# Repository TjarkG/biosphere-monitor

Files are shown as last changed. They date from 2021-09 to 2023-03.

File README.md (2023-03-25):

# Getting started with the Biosphere monitor command line tool

Get the repository and all its dependencies by running
`/bin/bash -c "$(curl -fsSL  https://raw.githubusercontent.com/TjarkG/biosphere-monitor/main/Shell/install.sh)"`

The Command line interface is started with `./biosphere`,
followed by a Port number (e.g. `/dev/ttyUSB0`) and optional arguments,
which can occur in any order, listed below:

* -h    show this help message
* -r    show current reading in Command line Output
* -rm   current output in machine-readable formate
* -s    show all saved readings. use pipes to save to a file
* -sc   same as -s, but with progress Updates on the Terminal. Use it to see the progress while piping
* -f    synchronize time
* -i    set measurement intervall in s, use -i? to get current intervall
* -t    run self test
* -ct   set current ambient Temperature(°C), used for Offset Calibration
* -delete delete Flash
* -gh   get current ADC reading of external input
* -ltn  set light on time, use -ltn? to get current setting
* -ltf  set light off time, use -ltf? to get current setting
* -lt   set light threshold, 0 for no threshold, use -lt? to get current setting

After cloning, generate makefiles with cmake:
```
mkdir cmake-build-debug
cd cmake-build-debug
cmake ..
```
and Compile the different programs:

* Command Line Tool: `make biosphere && ./biosphere /dev/ttyUSB0 -r`
* Graphical Configurator: `make bioGui`
* Microcontroller: `make Microcontroller.elf`

Check your data for Gaps with
`gawk -f Shell/gaps.awk gap=60 Documentation/Sample_Output.csv`
(gap is the intervall in s, each following argument is a Path to File to be checkt)

And convert it to an Excel Spreadsheet with
`soffice --convert-to xlsx --outdir ~/Dokumente/VS_Code/biosphere-monitor/Documentation Documentation/Sample_Output.csv --infilter=CSV:44,34,UTF8,true,3/10/4/10`

Complete Documentation (in German) can be found in /Documentation/Manual.pdf

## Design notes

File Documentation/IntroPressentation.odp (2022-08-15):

## Messgeräte für Biosphären

## Inhalt

- Was wird gemessen?
- Wofür braucht man das?
- Wie komme ich an die Daten?

## Was wird gemessen?

## Wofür braucht man das?

## Wie komme ich an die Daten?

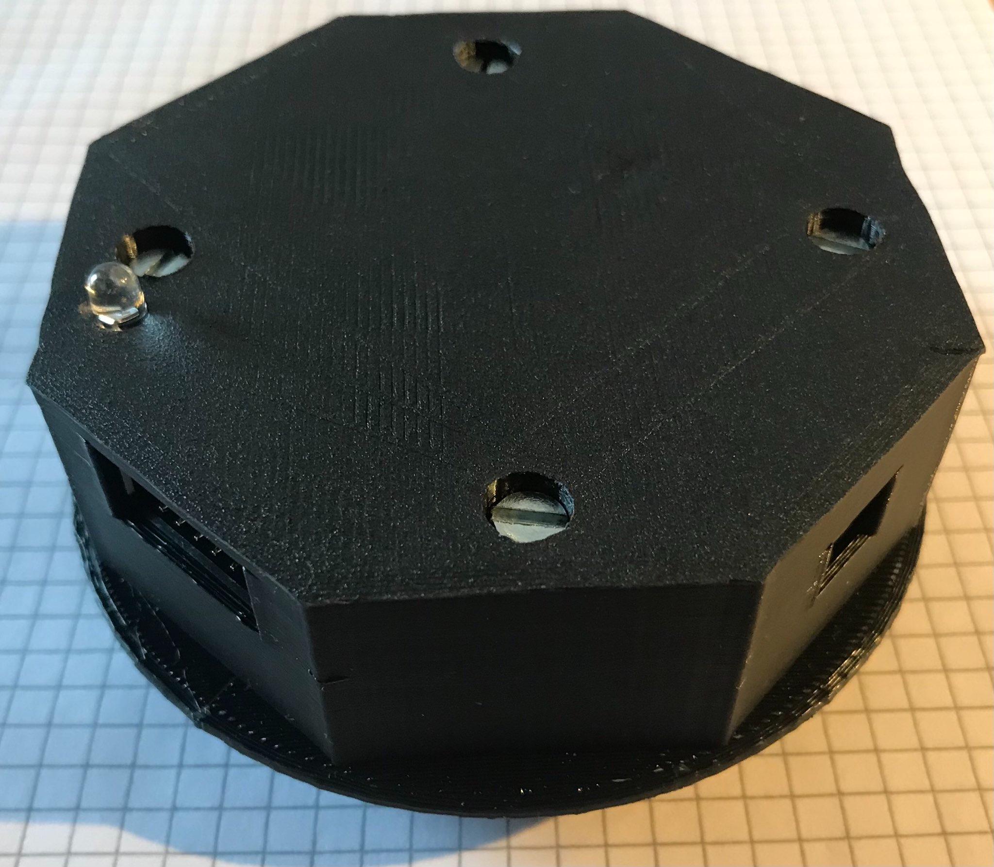
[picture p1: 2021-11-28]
Documentation/pic/Komplett.jpeg

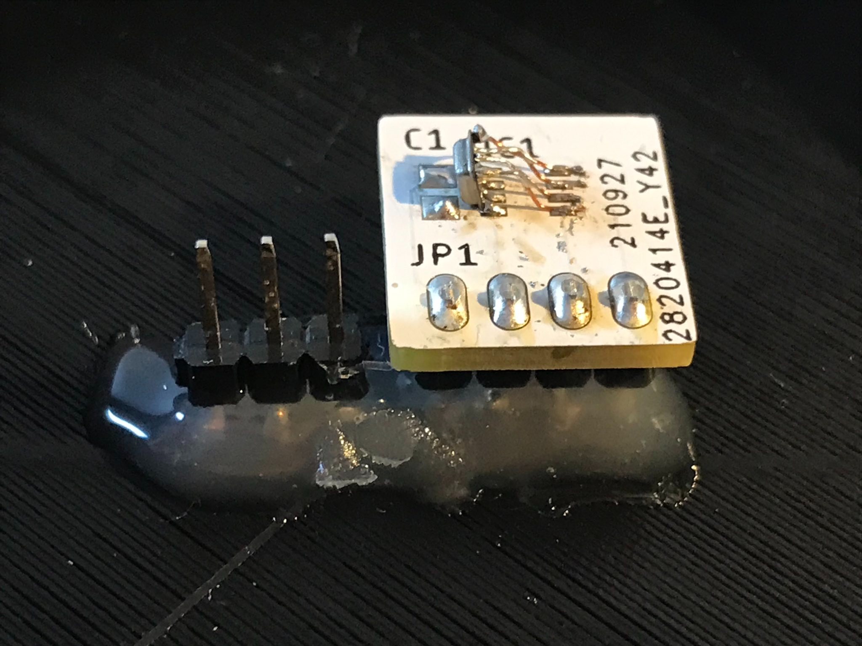
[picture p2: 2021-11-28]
Documentation/pic/Stiftleisten.jpeg

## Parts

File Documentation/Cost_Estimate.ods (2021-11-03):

Item | Preis /Stück | Preis / Fix |  | Preis mit vorhandenen Platinen etc.
Bauteile | 15,57 € | 5,95 € | Bauteile | 18,07 €
FTDI/USB | 1,98 € | 1,17 € | FTDI Adapter | 1,98 €
Platinen | 1,42 € | 14,03 € | Versand | 5,59 €
Filament | 0,00 € | 15,90 €
Schrauben | 2,99 € | 0,00 €
O Ring | 0,00 € | 0,00 €
 | 21,96 € | 37,05 € |  | 25,64 €

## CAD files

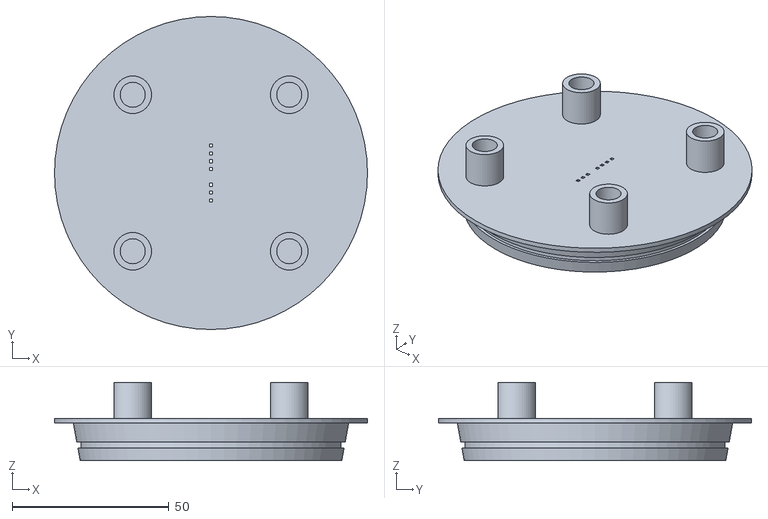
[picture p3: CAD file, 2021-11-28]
Hardware/MainPlate.stl
100.0 x 100.0 x 25.0

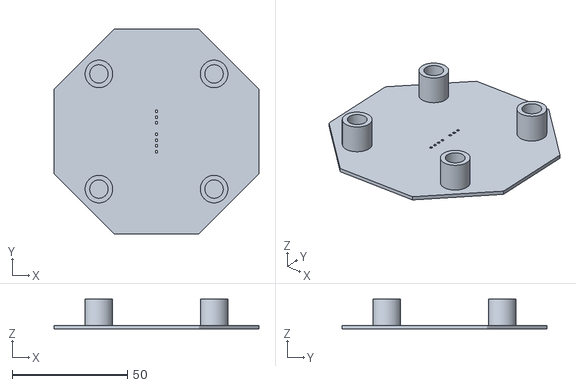
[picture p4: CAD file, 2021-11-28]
Hardware/MainPlateFlat.stl
89.0 x 89.0 x 13.0

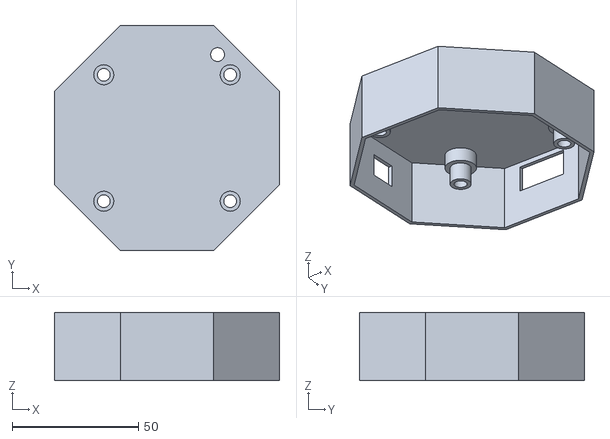
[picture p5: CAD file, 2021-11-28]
Hardware/Cap.stl
89.0 x 89.0 x 27.0

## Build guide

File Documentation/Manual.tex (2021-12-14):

\documentclass[12pt, a4paper, oneside]{report}
\usepackage[ngerman]{babel}
\usepackage{graphicx}
\usepackage{mathtools}
\usepackage{listings}
\usepackage{color}
\usepackage{float}
\sloppy
\usepackage[citecolor=black, colorlinks=true, urlcolor=blue, linkcolor=black]{hyperref}

\definecolor{mygreen}{rgb}{0,0.6,0}
\definecolor{mygray}{rgb}{0.5,0.5,0.5}
\definecolor{mymauve}{rgb}{0.58,0,0.82}
\definecolor{amber}{rgb}{0.8, 0.5, 0.2}

    \title{\textbf{Biosphären Mess- und Überwachungsgeräte -- Funktionsprinzipien und Bedienungsanleitung}}
    \author{Tjark Gaudich}
    \date{November 2021}
    
    \addtolength{\topmargin}{-2cm}
    \addtolength{\textheight}{2cm}
\begin{document}
\lstset{basicstyle=\footnotesize, language=C, keywordstyle=\color{blue}, tabsize=4}

\pagenumbering{Alph}
\begin{titlepage}
\maketitle
\thispagestyle{empty}
\end{titlepage}
\pagenumbering{arabic}

\section{Vorwort}
Das folgende Dokument soll gleichzeitig als Dokumentation und Bedienungsanleitung für die Biosphären Umweltmessgeräte ("die Geräte") dienen, die ich für den Astrobiologie Projektkurs 2021/2022 bei Herr Krobbach entwickelt habe. Damit soll eine Nutzung und Wartung dieser Geräte weit über den Zeitraum meiner Schullaufbahn hinaus ermöglicht werden. Besonderer Fokus wird deshalb auf die Kommunikation mit dem PC zum Auslesen der Messwerte gelegt, da dieser vulnerabel für Änderungen des Betriebssystems ist, doch auch alle anderen Aspekte der Geräte sollen so sehr vertieft werden, dass sie ohne großes Vorwissen verstanden und repariert werden können. Sämtliche Quelldateien sind zusammen mit dieser Dokumentation auf 
GitHub\cite{Github} frei zugänglich.
\tableofcontents
\listoffigures

\chapter{Mechanik}

Mechanisch lassen sich die Geräte in vier Komponenten unterteilen:
eine Grundplatte (in \autoref{fig:Querschnitt} Dunkelgrau), an der alle andere Teile und das Glas der Biosphäre befestigt werden, eine Platine mit Sensoren im Inneren (nicht gezeigt) und die Hauptplatine (grün) außen sowie ein Deckel (hellgrau), der die Elektronik vor Beschädigungen schützt.
\begin{figure}[h]
	\centering
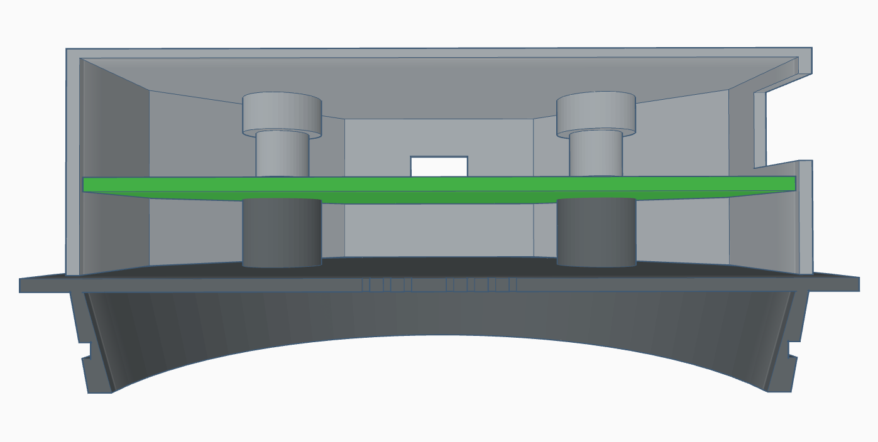
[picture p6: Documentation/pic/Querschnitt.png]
	
	\caption{Querschnitt durch das Gerät}
	\label{fig:Querschnitt}
\end{figure}
\\Auf die Platinen wird in \autoref{ch:elektronik} näher eingegangen, hier reicht es uns zu wissen das die unterer Platine nur über ihren Stecker befestigt wird und die obere ein Achteck von 85mm Durchmesser ist, vier Löcher mit je 50mm Abstand zueinander und 4mm Durchmesser zur Befestigung hat und 1,6mm Dick ist.

Deckel und Grundplatte sind beide aus PLA 3d gedruckt. Dabei wurde eine Auflösung von 0,2mm bei 100\% Infill verwendet
\section{Grundplatte}
Entsprechend dieser Maße ist die Oberseite der Grundplatte mit vier Röhren ausgestattet, in die M4 Einschraubmuffen montiert werden. Interessant ist jedoch die Unterseite, die in das Gurkenglas eingeklebt wird. Da die Luftmenge in der Biosphäre konstant ist kommt es bei Temperaturänderungen zu einer Druckänderung nach  dem Gesetz von Amontons \cite[S.~119]{Tafelwerk}, denen die Grundplatte und ihre Verklebung standhalten müssen. $p_0$ und $T_0$ sind dabei Druck und absolute Temperatur beim Verschließen der Biosphäre.
\begin{align}
\frac{p_0}{T_0} = \frac{p_1}{T_1} \footnote{}
\iff \Delta p = T  \times \frac{p_0}{T_0} - p_0
\label{eq:pressure}
\end{align}
Nehmen wir an, das die Biosphäre bei 20°C (293K) und Normaldruck verschlossen wurde und sich im Schlimmsten Falle auf 100°C (373K) aufgeheizt hat (darüber ist ihr Inhalt vermutlich tot, weshalb die Abdichtung irrelevant wird),
\begin{align}
\Delta p = 373K  \times \frac{1013hPa}{293K} - 1013hPa \approx 277hPa
\label{eq:pressure100C}
\end{align}
so ergibt sich nach \autoref{eq:pressure100C} ein Druckunterschied von 277hPa. Diese Druckfestigkeit mit einer Silikon Verklebung zu erreichen ist relativ einfach, beim Übergang zwischen Grundplatte und anschließendem Ring wird sie jedoch zu Herausforderung. Um eine höhere Festigkeit zu erreichen wurde dieser Übergang nach dem Druck zusätzlich mit einem Lötkolben verschmolzen. Diese Kombination hielt beim Anschließen eines Kompressors an einen Modifizierten Deckel etwa 300hPa Überdruck stand.

Falls sich zeigen sollte, das dies nicht ausreicht wäre eine Verdickung des Übergangs oder der Druck aus einem festeren Material, z.B.~Nylon, empfehlenswert.

Bei der Verklebung der Grundplatte mit dem Glas der Biosphäre sollte Aquariensilikon verwendet werden, da Sanitärsilikon für die Oranismen in der Biosphäre schädliche Zusatzstoffe enthalten kann.

\begin{figure}[h]
	\centering
	
	\caption{Fertig montierte Stiftleisten mit Sensorplatine}
	\label{fig:Stiftleisten}
\end{figure}

In der Platte befinden sich sieben Löcher, durch die Stiftleisten gesteckt werden um die Sensoren im Inneren mit der Hauptplatine zu verbinden. Dabei wird eine Stiftleiste von oben eingesteckt, mit Epoxidharz (UHU Endfest 3000) verklebt, von unten eine weitere Stiftleiste angelötet und die Lötstelle mit Heißkleber fixiert.

\section{Deckel}
Der Deckel besteht aus einem Achteck mit Abschlussplatte und eingesenkten Löchern, durch die er und die Hauptplatine mit vier M4~x~16 Schrauben an der Grundplatte befestigt werden. Beim Entfernen muss darauf geachtet werden, dass keine Kabel eingesteckt sind und der Deckel gerade nach oben abgezogen wird, um die durch ihn vorstehende Fotodiode nicht zu beschädigen.
\\
\begin{figure}[h]
	\centering
	
	\caption{Vollständig montiertes Gerät}
	\label{fig:Komplett}
\end{figure}

\chapter{Elektronik}
\label{ch:elektronik}
Die Elektronik besteht aus der Hauptplatine, die in fünf Funktionsblöcke unterteilt ist, einer Adapterplatine für den Luftsensor und einem ansteckbaren Bodenfeuchtigkeitssensor. Die Funktionsblöcke ensprechen den Seiten von "`biosphereMonitor.sch"', die Adapterplatine findet sich in "`Adapter.sch"'. Beide Schaltpläne und ihre dazugehörigen Platinen sind mit Eagle verfasst worden.

Eagle ist als Demoversion und für Bildungszwecke kostenlos und lässt sich unter \url{https://www.autodesk.de/products/eagle/free-download}\\ herunterladen.
\section{Mikrocontroller}
\label{sec:Mikrocontroller}
Alls Mikroncontroller findet ein ATxmega32A4AU\cite{ds:xmega} oder 16A4AU von Microchip Verwendung (IC1).

\begin{figure}[h]
	\centering
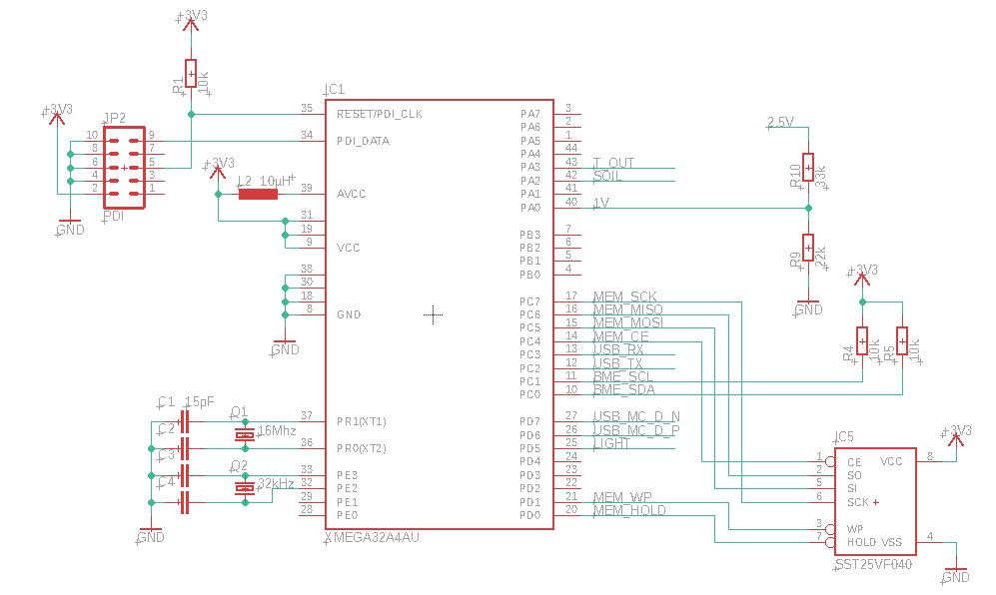
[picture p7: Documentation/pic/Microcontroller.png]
	
	\caption{Schaltplan Mikrocontroller}
	\label{fig:Microcontroller}
\end{figure}

\begin{figure}[h]
	\centering
\begin{tabular}{c|l}
	Pins & Funktion\\
	\hline
	10, 11 & TWI C zum Luftsensoren (\autoref{sec:Adapterplatine})\\
	12 (Tx), 13 (Rx)& UART0 zum USB UART Wandler (\autoref{sec:USB-UART Wandler}), \\&in Revision 1.0 vertauscht\\
	14 - 17 & Flash Spi Schnittstelle\\
	20, 21 & Flash Kontrollsignale\\
	25 & Lichtsensor (\autoref{sec:Außensensoren}), bei Steigender Flanke \\&Pin Change Interuppt\\
	26, 27 & Reserviert für eingebautes USB\\
	32, 33 & Q2, 32.768kHz Uhrenquartz für die Realtimeclock\\
	34, 35 & PDI Programmierschittstelle\\
	36, 37 & Q1, 4 - 20MHz Hauptquartz, (16MHz Standard)\\
	40 & 1V Referenzspannung, über R9/10 aus 2,5V\\
	42 & ADC In Bodenfeuchtigkeitssensor (s. \autoref{sec:Bodenfeuchtigkeitssensor}) \\
	43 & ADC In Temperatursensor (s. \autoref{sec:Außensensoren})\\
\end{tabular}
	\caption{Pinbelegung Mikrocontroller}
\end{figure}
Dieser wird über die PDI Schnittstelle auf JP2 Programmiert. Das Pinout dieses Steckers ist kompaktibel mit dem des AVR ISP MK II Programiergeräts von Atmel/Microchip.
Die Frequenz von Q1 muss in $main.c$ und $makefile$ als F\_CPU eingetragen werden

Beim Flash handelt es sich um einen 4Mb 

\section{Stromverteilung}
\label{sec:Stromverteilung}

\section{USB-UART Wandler}
\label{sec:USB-UART Wandler}

\pagebreak
\section{Außensensoren}
\label{sec:Außensensoren}
Außen werden zwei Messwerte erhoben: Temperatur und Helligkeit.

Die Temperatur wird mit einem analogen Temperatursensor vom Typ LM35 \cite{ds:temp} der an TP6 eine Spannung von
$ 10mV * t~(in~^\circ C)$ anlegt. Diese wird vom Mikrocontroller (\autoref{sec:Mikrocontroller}) gemessen.

\begin{figure}[h]
	\centering
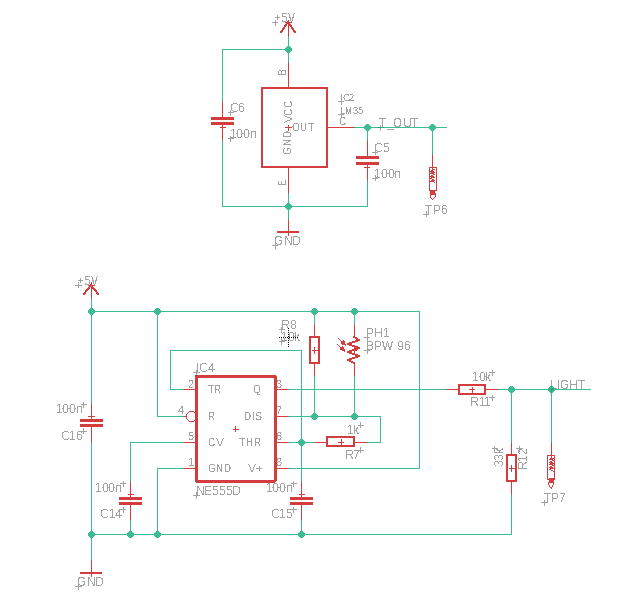
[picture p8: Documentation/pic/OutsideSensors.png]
	
	\caption{Schaltplan Außensensoren}
	\label{fig:Außensensor}
\end{figure}

Die Helligkeit wird mit einer Fotodiode vom Typ BPW96 \cite{ds:light} gemessen, die parralel zu R8 im Timingpfad des NE555 eingebaut ist. R11 und 12 teilen die Spannung des Ausgangssignales von 5V auf 3,3V, so das an TP7 ein 3,3V Rechtecksignal mit einer Frequenz exponential zur Lichteinstrahlung anliegt. Um die Einstrahlung zu bestimmen ist im Mikrocontroller eine Funktion fest einprogrammiert, die anhand der Messreihe aus $Lux~Messurments.ods$ bestimmt wurde. Die Formel hat das Format $f(x)=a \cdot x^b + c$. Um diese Formel zu füllen werden zunächst drei Punkte, erster, letzter und mittlerer aus der Messreihe, ausgewählt.

\begin{figure}[h]
\centering
\begin{tabular}{c|c|c}
	Nr. & x & y\\
	\hline
	1 & 1,27 & 0\\
	2 & 3,93 & 442\\
	3 & 6,21 & 1880\\
\end{tabular}
\end{figure}

Diese werden in \autoref{eq:lightB} bis \ref{eq:lightC} eingsetzt, um \autoref{eq:light} zu erhalten. Die dadurch erreichte Annäherung ist in \autoref{fig:Licht} oder $Lux~Messurments.ods$\footnote{\url{https://github.com/TjarkG/biosphere-monitor/blob/main/Documentation/Lux\%20Messurments.ods}} zu erkennen.

\begin{align}
y_3-y_1=\frac{y_2-y_1}{b^{x_2}-b^{x_1}}\cdot(b^{x_3}-b^{x_1}) \iff b \approx 1,65
\label{eq:lightB}
\end{align}

\begin{align}
a=\frac{y_2-y_1}{b^{x_2}-b^{x_1}} = 83,75
\label{eq:lightA}
\end{align}

\begin{align}
c = -a\cdot b^{x_1} + y_1 = -158,26
\label{eq:lightC}
\end{align}

\begin{align}
\label{eq:light}
f(x) = 83,75 \cdot 1,65^x -158,26
\end{align}

\begin{figure}[H]
	\centering
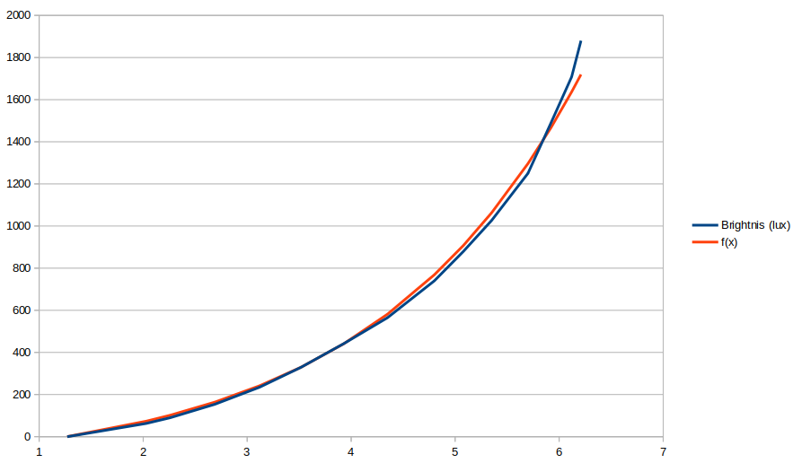
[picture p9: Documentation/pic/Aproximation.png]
	
	\caption{Annäherung Messwerte}
	\label{fig:Licht}
\end{figure}
\pagebreak
Dieser Werte sind auch in die Entsprechende Funktion in $main.c$\footnote{\url{https://github.com/TjarkG/biosphere-monitor/blob/main/Microcontroller/main.c}} eingesetzt
Sie sind momentan fest einprogrammiert, auch wenn eine Möglichkeit sie zu konfigurieren sinnvoll wäre.
\begin{lstlisting}
unsigned int getLight(void)  //returns iluminace in lux
{
	if(lightFnom < 1200)     //Sensor cutoff Frequency
		return 0;
	return ((66.46 * pow(1.732, (lightFnom/1000.0)) ) - 133.5);
}
\end{lstlisting}

\section{Anschlüsse Innensensoren}
\label{sec:Innensensoren}

\section{Adapterplatine}
\label{sec:Adapterplatine}

\section{Bodenfeuchtigkeitssensor}
\label{sec:Bodenfeuchtigkeitssensor}

\chapter{Software}
Die Software besteht aus zwei Teilen, dem Code für den Mikrocontroller und dem Ausleseprogramm für den PC. Um die eine installieren und die andere nutzen zu können müssen beide zunächst gecloned und ihre abhängigkeiten installiert werden. Die Befehle können für Debian Linux Varianten einfach kopiert werden, für andere Distributionen oder MacOS ist \lstinline|sudo apt-get| durch das lokale Eqvivallent zu ersetzen
\section{Instalation}
\label{sec:Instalation}
Sämtliche benötigte Software kann durch ausführen von
\begin{lstlisting}
/bin/bash -c "$(curl -fsSL 
https://raw.githubusercontent.com/
TjarkG/biosphere-monitor/main/Shell/install.sh)"
\end{lstlisting}
Installiert werden. Der Script wurde unter Ubuntu und Alpine Linux getestet. Falls dies nicht funktioniert kann die Installation auch manuel durchgeführt werden:
Zum Clonen muss zunächst $git$ installiert werden.
\begin{lstlisting}
$ sudo apt-get install git
\end{lstlisting}
Dann kann das Repository gecloned
\begin{lstlisting}
$ git clone https://github.com/TjarkG/biosphere-monitor
\end{lstlisting}
Und in den neuen Ortnder gewechselt werden.
\begin{lstlisting}
$ cd biosphere-monitor
\end{lstlisting}
Um die PC Software compilen zu können ist außerdem GCC als Kompiler notwendig.
\begin{lstlisting}
$ sudo apt-get install gcc
\end{lstlisting}
Die aktuelle Version kann jetzt jeweils mit
\begin{lstlisting}
$ cc PC/biosphere.c -o PC/biosphere
$ ./PC/biosphere /dev/ttyUSB0 -r
\end{lstlisting}
kompilert und ausgeführt werden. 
\pagebreak

Um die Mikrocontroller Firmware aktualisieren zu können, werden neben der Hardware (\autoref{sec:Mikrocontroller})  eine ganze Reihe Hilfsprogramme benötigt. Eine Erläuterungen zu ihrer Funktion findet sich unter \cite{UbuntuAVR}
\begin{lstlisting}
$ sudo apt-get install avr-libc binutils-avr gcc-avr avrdude make
\end{lstlisting}
Das Upload der Firmware erfolgt mit
\begin{lstlisting}
$ make program -C ./Microcontroller
\end{lstlisting}

\section{Mikrocontroller}
\section{PC}
\section{Scripte}
Im Ordner $Shell$ befinden sich zwei Scripte:
$install.sh$ ist der installationsscript der in \autoref{sec:Instalation} verwendet wurde. 
Dieser führt die selben Schritte aus die auch dort beschrieben sind, 
ermittelt allerdings von selber den verwendeten Paketmanager.

Des weiteren ist $kiosk.sh$ enthalten.
Dieser Script hohlt sich einmal pro Sekunde von $biosphere.c$ die aktuellen Messwerte für das Messgerät 
an $/dev/ttyUSB0$ und zeigt sie auf dem Terminal an.
\begin{thebibliography}{9}
\raggedright 

\bibitem{Github}
  Tjark Gaudich,
  \textit{Biospher Monitor},\\
  \url{github.com/TjarkG/biosphere-monitor}\\
  GitHub.com,
  2021
  
\bibitem{Tafelwerk}
  Prof.~Dr.~Lothar Meyer et al.,
  \textit{Das große Tafelwerk interaktiv 2.0},
  Cornelsen Verlag, Berlin,
  1. Auflage, 8. Druck 2018
  
\bibitem{ds:xmega}
  Microchip Technology Inc.,
  \textit{ATxmega32A4U datasheet},\\
  \url{www.microchip.com/downloads/en/DeviceDoc/ATxmega128-64-32-16A4U-DataSheet-DS40002166A.pdf}\\
  Microchip.com,
  2011-2020
  
\bibitem{ds:Flash}
  Microchip Technology Inc.,
  \textit{SST25VF040 datasheet},\\
  \url{www.microchip.com/downloads/en/DeviceDoc/20005051E.pdf}\\
  Microchip.com,
  2005-2020
  
\bibitem{ds:usb}
  Future Technology Devices International Limited,
  \textit{FT2323R datasheet},\\
  \url{www.ftdichip.com/wp-content/uploads/2020/08/DS_FT232R.pdf}\\
  ftdichip.com, 2020
  
\bibitem{ds:temp}
  Texas Instruments Incorporated,
  \textit{LM35 datasheet},\\
  \url{www.ti.com/lit/gpn/lm35}\\
  TI.com,
  1999-2017
  
\bibitem{ds:light}
  Vishay Semiconductors,
  \textit{BPW96 datasheet},\\
  \url{www.vishay.com/docs/81532/bpw96.pdf}\\
  vishay.com,
  2011
  
\bibitem{ds:BMP280}
  Bosch Sensortec GmbH,
  \textit{BMP280 datasheet},\\
  \url{www.bosch-sensortec.com/media/boschsensortec/downloads/datasheets/bst-bmp280-ds001.pdf}\\
  bosch-sensortec.com,
  Oktober 2021
  
\bibitem{ds:BME280}
  Bosch Sensortec GmbH,
  \textit{BME280 datasheet},\\
  \url{www.bosch-sensortec.com/media/boschsensortec/downloads/datasheets/bst-bme280-ds002.pdf}\\
  bosch-sensortec.com,
  Oktober 2021
  
\bibitem{ds:BME680}
  Bosch Sensortec GmbH,
  \textit{BME680 datasheet},\\
  \url{www.bosch-sensortec.com/media/boschsensortec/downloads/datasheets/bst-bme680-ds001.pdf}\\
  bosch-sensortec.com,
  Januar 2021

\bibitem{CLanguage}
  Brian W.Kernighan, Dennis M.Ritchie,
  \textit{The C Programming Language},
  Prentice Hall PTR, New Jersey,
  2. Auflage, 58. Druck 2018
  
\bibitem{UbuntuAVR}
  Ubuntu Wiki,
  \textit{AVR},\\
  \url{https://wiki.ubuntuusers.de/AVR/}\\
  Ubuntu Deutschland e.V.,
  Januar 2021

\end{thebibliography}

\end{document}

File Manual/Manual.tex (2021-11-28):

\documentclass[12pt, a4paper, oneside]{report}
\usepackage[ngerman]{babel}
\usepackage{graphicx}
\usepackage{mathtools}
\usepackage[citecolor=black, colorlinks=true, urlcolor=blue, linkcolor=black]{hyperref}
    \title{\textbf{Biosphären Mess- und Überwachungsgeräte -- Funktionsprinzipien und Bedienungsanleitung}}
    \author{Tjark Gaudich}
    \date{November 2021}
    
    \addtolength{\topmargin}{-2cm}
    \addtolength{\textheight}{2cm}
\begin{document}
\maketitle

\section{Vorwort}
Das folgende Dokument soll gleichzeitig als Dokumentation und Bedienungsanleitung für die Biosphären Umweltmessgeräte ("die Geräte") dienen, die ich für den Astrobiologie Projektkurs 2021/2022 bei Herr Krobbach entwickelt habe. Damit soll eine Nutzung und Wartung dieser Geräte weit über den Zeitraum meiner Schullaufbahn hinaus ermöglicht werden. Besonderer Fokus wird deshalb auf die Kommunikation mit dem PC zum Auslesen der Messwerte gelegt, da dieser vulnerabel für Änderungen des Betriebssystems ist, doch auch alle anderen Aspekte der Geräte sollen so sehr vertieft werden, dass sie ohne großes Vorwissen verstanden und repariert werden können. Sämtliche Quelldateien sind zusammen mit dieser Dokumentation auf 
GitHub\cite{Github} frei zugänglich.
\tableofcontents
\listoffigures

\chapter{Mechanik}

Mechanisch lassen sich die Geräte in vier Komponenten unterteilen:
eine Grundplatte (in \autoref{fig:Querschnitt} Dunkelgrau), an der alle andere Teile und das Glas der Biosphäre befestigt werden, eine Platine mit Sensoren im Inneren (nicht gezeigt) und die Hauptplatine (grün) außen sowie ein Deckel (hellgrau), der die Elektronik vor Beschädigungen schützt.
\begin{figure}[h]
	\centering
	
	\caption{Querschnitt durch das Gerät}
	\label{fig:Querschnitt}
\end{figure}
\\Auf die Platinen wird in \autoref{ch:elektrisch} näher eingegangen, hier reicht es uns zu wissen das die unterer Platine nur über ihren Stecker befestigt wird und die obere ein Achteck von 85mm Durchmesser ist, vier Löcher mit je 50mm Abstand zueinander und 4mm Durchmesser zur Befestigung hat und 1,6mm Dick ist.

Deckel und Grundplatte sind beide aus PLA 3d gedruckt. Dabei wurde eine Auflösung von 0,2mm bei 100\% Infill verwendet
\section{Grundplatte}
Entsprechend dieser Maße ist die Oberseite der Grundplatte mit vier Röhren ausgestattet, in die M4 Einschraubmuffen montiert werden. Interessant ist jedoch die Unterseite, die in das Gurkenglas eingeklebt wird. Da die Luftmenge in der Biosphäre konstant ist kommt es bei Temperaturänderungen zu einer Druckänderung nach  dem Gesetz von Amontons \cite[S.~119]{Tafelwerk}, denen die Grundplatte und ihre Verklebung standhalten müssen. $p_0$ und $T_0$ sind dabei Druck und absolute Temperatur beim Verschließen der Biosphäre.
\begin{align}
\frac{p_0}{T_0} = \frac{p_1}{T_1} \footnote{}
\iff \Delta p = T  \times \frac{p_0}{T_0} - p_0
\label{eq:pressure}
\end{align}
Nehmen wir an, das die Biosphäre bei 20°C (293K) und Normaldruck verschlossen wurde und sich im Schlimmsten Falle auf 100°C (373K) aufgeheizt hat (darüber ist ihr Inhalt vermutlich tot, weshalb die Abdichtung irrelevant wird),
\begin{align}
\Delta p = 373K  \times \frac{1013hPa}{293K} - 1013hPa \approx 277hPa
\label{eq:pressure100C}
\end{align}
so ergibt sich nach \autoref{eq:pressure100C} ein Druckunterschied von 277hPa. Diese Druckfestigkeit mit einer Silikon Verklebung zu erreichen ist relativ einfach, beim Übergang zwischen Grundplatte und anschließendem Ring wird sie jedoch zu Herausforderung. Um eine höhere Festigkeit zu erreichen wurde dieser Übergang nach dem Druck zusätzlich mit einem Lötkolben verschmolzen. Diese Kombination hielt beim Anschließen eines Kompressors an einen Modifizierten Deckel etwa 300hPa Überdruck stand.

Falls sich zeigen sollte, das dies nicht ausreicht wäre eine Verdickung des Übergangs oder der Druck aus einem festeren Material, z.B.~Nylon, empfehlenswert.

\begin{figure}[h]
	\centering
	
	\caption{Fertig montierte Stiftleisten mit Sensorplatine}
	\label{fig:Stiftleisten}
\end{figure}

In der Platte befinden sich sieben Löcher, durch die Stiftleisten gesteckt werden um die Sensoren im Inneren mit der Hauptplatine zu verbinden. Dabei wird eine Stiftleiste von oben eingesteckt, mit Epoxidharz (UHU Endfest 3000) verklebt, von unten eine weitere Stiftleiste angelötet und die Lötstelle mit Heißkleber fixiert.

\section{Deckel}
Der Deckel besteht aus einem Achteck mit Abschlussplatte und eingesenkten Löchern, durch die er und die Hauptplatine mit vier M4~x~16 Schrauben an der Grundplatte befestigt werden. Beim Entfernen muss darauf geachtet werden, dass keine Kabel eingesteckt sind und der Deckel gerade nach oben abgezogen wird, um die durch ihn vorstehende Fotodiode nicht zu beschädigen.
\\
\begin{figure}[h]
	\centering
	
	\caption{Vollständig montiertes Gerät}
	\label{fig:Komplett}
\end{figure}

\chapter{elektrisch}
\label{ch:elektrisch}
\chapter{Software}

\begin{thebibliography}{9}

\bibitem{Github}
  Tjark Gaudich,
  \textit{\url{https://github.com/TjarkG/biosphere-monitor}},
  GitHub.com,
  2021
  
\bibitem{Tafelwerk}
  Prof.~Dr.~Lothar Meyer et al.,
  \textit{Das große Tafelwerk interaktiv 2.0},
  Cornelsen Verlag, Berlin,
  1.Auflage, 8. Druck 2018

\end{thebibliography}

\end{document}

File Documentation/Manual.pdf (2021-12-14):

# Biosphären Mess- und

Uberwachungsger ¨ | äte –

# Funktionsprinzipien und Bedienungsanleitung

### Tjark Gaudich

### November 2021

## 0.1 Vorwort

Das folgende Dokument soll gleichzeitig als Dokumentation und Bedienungs-
anleitung fur die Biosph ¨ | ären Umweltmessgeräte (”die Geräte”) dienen, die
ich fur den Astrobiologie Projektkurs 2021/2022 bei Herr Krobbach entwi- ¨ ckelt habe. Damit soll eine Nutzung und Wartung dieser Geräte weit uber den ¨ Zeitraum meiner Schullaufbahn hinaus ermöglicht werden. Besonderer Fokus wird deshalb auf die Kommunikation mit dem PC zum Auslesen der Messwerte gelegt, da dieser vulnerabel fur ¨ Anderungen des Betriebssystems ist, doch ¨ auch alle anderen Aspekte der Geräte sollen so sehr vertieft werden, dass sie ohne großes Vorwissen verstanden und repariert werden können. Sämtliche Quelldateien sind zusammen mit dieser Dokumentation auf GitHub[1] frei zugänglich.

# Inhaltsverzeichnis

1 Mechanik | 4
2 Elektronik | 7
3 Software | 12

2

# Abbildungsverzeichnis

1.1 Querschnitt durch das Gerät | | 4
1.2 Fertig montierte Stiftleisten mit Sensorplatine | | 5
1.3 Vollständig montiertes Gerät | | 6
2.1 Schaltplan Mikrocontroller | | 7
2.2 Pinbelegung Mikrocontroller | | 8
2.3 Schaltplan Außensensoren | | 9
2.4 Annäherung Messwerte | 10

3

# Kapitel 1

# Mechanik

Mechanisch lassen sich die Geräte in vier Komponenten unterteilen: eine Grundplatte (in Abbildung 1.1 Dunkelgrau), an der alle andere Teile und das Glas der Biosphäre befestigt werden, eine Platine mit Sensoren im Inneren (nicht gezeigt) und die Hauptplatine (grun) außen sowie ein Deckel (hellgrau), ¨ der die Elektronik vor Beschädigungen schutzt. ¨


Abbildung 1.1: Querschnitt durch das Gerät

Auf die Platinen wird in Kapitel 2 näher eingegangen, hier reicht es uns zu wissen das die unterer Platine nur uber ihren Stecker befestigt wird und ¨ die obere ein Achteck von 85mm Durchmesser ist, vier Löcher mit je 50mm Abstand zueinander und 4mm Durchmesser zur Befestigung hat und 1,6mm Dick ist.
Deckel und Grundplatte sind beide aus PLA 3d gedruckt. Dabei wurde eine Auflösung von 0,2mm bei 100% Infill verwendet

4

## 1.1 Grundplatte

Entsprechend dieser Maße ist die Oberseite der Grundplatte mit vier Röhren ausgestattet, in die M4 Einschraubmuffen montiert werden. Interessant ist jedoch die Unterseite, die in das Gurkenglas eingeklebt wird. Da die Luftmenge in der Biosphäre konstant ist kommt es bei Temperaturänderungen zu einer Druckänderung nach dem Gesetz von Amontons [2, S. 119], denen die Grundplatte und ihre Verklebung standhalten mussen. ¨ p0 und T0 sind dabei Druck und absolute Temperatur beim Verschließen der Biosphäre.
p0
T0

=

p1
T1

1 ⇐⇒ ∆p = T ×

p0
T0
− p0 | (1.1)

Nehmen wir an, das die Biosphäre bei 20°C (293K) und Normaldruck verschlossen wurde und sich im Schlimmsten Falle auf 100°C (373K) aufgeheizt hat (daruber ist ihr Inhalt vermutlich tot, weshalb die Abdichtung irrelevant ¨ wird),

∆p = 373K ×

1013hP a
293K
− 1013hP a ≈ 277hP a | (1.2)

so ergibt sich nach Gleichung 1.2 ein Druckunterschied von 277hPa. Diese Druckfestigkeit mit einer Silikon Verklebung zu erreichen ist relativ einfach, beim Ubergang zwischen Grundplatte und anschließendem Ring wird ¨ sie jedoch zu Herausforderung. Um eine höhere Festigkeit zu erreichen wurde
dieser Ubergang nach dem Druck zus ¨ | ätzlich mit einem Lötkolben verschmol-
zen. Diese Kombination hielt beim Anschließen eines Kompressors an einen Modifizierten Deckel etwa 300hPa Uberdruck stand. ¨
Falls sich zeigen sollte, das dies nicht ausreicht wäre eine Verdickung des Ubergangs oder der Druck aus einem festeren Material, z.B. Nylon, empfeh- ¨ lenswert.
Bei der Verklebung der Grundplatte mit dem Glas der Biosphäre sollte Aquariensilikon verwendet werden, da Sanitärsilikon fur die Oranismen in ¨ der Biosphäre schädliche Zusatzstoffe enthalten kann.


Abbildung 1.2: Fertig montierte Stiftleisten mit Sensorplatine

In der Platte befinden sich sieben Löcher, durch die Stiftleisten gesteckt werden um die Sensoren im Inneren mit der Hauptplatine zu verbinden. Dabei wird eine Stiftleiste von oben eingesteckt, mit Epoxidharz (UHU Endfest

5

3000) verklebt, von unten eine weitere Stiftleiste angelötet und die Lötstelle mit Heißkleber fixiert.

## 1.2 Deckel

Der Deckel besteht aus einem Achteck mit Abschlussplatte und eingesenkten Löchern, durch die er und die Hauptplatine mit vier M4 x 16 Schrauben an der Grundplatte befestigt werden. Beim Entfernen muss darauf geachtet werden, dass keine Kabel eingesteckt sind und der Deckel gerade nach oben abgezogen wird, um die durch ihn vorstehende Fotodiode nicht zu beschädigen.


Abbildung 1.3: Vollständig montiertes Gerät

6

# Kapitel 2

# Elektronik

Die Elektronik besteht aus der Hauptplatine, die in funf Funktionsbl ¨ | öcke
unterteilt ist, einer Adapterplatine fur den Luftsensor und einem ansteck- ¨ baren Bodenfeuchtigkeitssensor. Die Funktionsblöcke ensprechen den Seiten von ”
biosphereMonitor.sch“, die Adapterplatine findet sich in ” | Adapter.sch“.
Beide Schaltpläne und ihre dazugehörigen Platinen sind mit Eagle verfasst worden.
Eagle ist als Demoversion und fur Bildungszwecke kostenlos und l ¨ | ässt sich
unter https://www.autodesk.de/products/eagle/free-download herunterladen.

## 2.1 Mikrocontroller

Alls Mikroncontroller findet ein ATxmega32A4AU[3] oder 16A4AU von Microchip Verwendung (IC1).


Abbildung 2.1: Schaltplan Mikrocontroller

7

Pins | Funktion
10, 11 | TWI C zum Luftsensoren (Abschnitt 2.6)
12 (Tx), 13 (Rx) | UART0 zum USB UART Wandler (Abschnitt 2.3),
| in Revision 1.0 vertauscht
14 - 17 | Flash Spi Schnittstelle
20, 21 | Flash Kontrollsignale
25 | Lichtsensor (Abschnitt 2.4), bei Steigender Flanke
| Pin Change Interuppt
26, 27 | Reserviert fur eingebautes USB ¨
32, 33 | Q2, 32.768kHz Uhrenquartz fur die Realtimeclock ¨
34, 35 | PDI Programmierschittstelle
36, 37 | Q1, 4 - 20MHz Hauptquartz, (16MHz Standard)
40 | 1V Referenzspannung, uber R9/10 aus 2,5V ¨
42 | ADC In Bodenfeuchtigkeitssensor (s. Abschnitt 2.7)
43 | ADC In Temperatursensor (s. Abschnitt 2.4)

Abbildung 2.2: Pinbelegung Mikrocontroller

Dieser wird uber die PDI Schnittstelle auf JP2 Programmiert. Das Pi- ¨ nout dieses Steckers ist kompaktibel mit dem des AVR ISP MK II Programiergeräts von Atmel/Microchip. Die Frequenz von Q1 muss in main.c und makef ile als F CPU eingetragen werden
Beim Flash handelt es sich um einen 4Mb

## 2.2 Stromverteilung

## 2.3 USB-UART Wandler

8

## 2.4 Außensensoren

Außen werden zwei Messwerte erhoben: Temperatur und Helligkeit.
Die Temperatur wird mit einem analogen Temperatursensor vom Typ LM35 [6] der an TP6 eine Spannung von 10mV ∗ t (in ◦C) anlegt. Diese wird vom Mikrocontroller (Abschnitt 2.1) gemessen.


Abbildung 2.3: Schaltplan Außensensoren

Die Helligkeit wird mit einer Fotodiode vom Typ BPW96 [7] gemessen, die parralel zu R8 im Timingpfad des NE555 eingebaut ist. R11 und 12 teilen die Spannung des Ausgangssignales von 5V auf 3,3V, so das an TP7 ein 3,3V Rechtecksignal mit einer Frequenz exponential zur Lichteinstrahlung anliegt. Um die Einstrahlung zu bestimmen ist im Mikrocontroller eine Funktion fest einprogrammiert, die anhand der Messreihe aus Lux Messurments.ods bestimmt wurde. Die Formel hat das Format f(x) = a · x

b + c. Um diese
Formel zu fullen werden zun ¨ | ächst drei Punkte, erster, letzter und mittlerer
aus der Messreihe, ausgewählt.
Nr. | x | y
1 | 1,27 | 0
2 | 3,93 | 442
3 | 6,21 | 1880

9

Diese werden in Gleichung 2.1 bis 2.3 eingsetzt, um Gleichung 2.4 zu erhalten. Die dadurch erreichte Annäherung ist in Abbildung 2.4 oder Lux Messurments.ods¹
zu erkennen.

y3 − y1 =

y2 − y1
b

x2 − b

x1

- (b

x3 − b

x1
) ⇐⇒ b ≈ 1, 65 | (2.1)

a =

y2 − y1
b

x2 − b

x1

= 83, 75 | (2.2)

c = −a · b

x1 + y1 = −158, 26 | (2.3)
f(x) = 83, 75 · 1, 65x − 158, 26 | (2.4)


Abbildung 2.4: Annäherung Messwerte

1https://github.com/TjarkG/biosphere-monitor/blob/main/Documentation/Lux%20Messurments.ods (https://github.com/TjarkG/biosphere-monitor/blob/main/Documentation/Lux%20Messurments.ods)

10

Dieser Werte sind auch in die Entsprechende Funktion in main.c² eingesetzt Sie sind momentan fest einprogrammiert, auch wenn eine Möglichkeit sie zu konfigurieren sinnvoll wäre.

un si gned i n t g e t Li g h t ( v oid ) // r e t u r n s il um i n a c e in l u x
{
i f ( lightFnom < 1 2 0 0 ) | // Sensor c u t o f f Frequency
r e t u r n 0 ;
r e t u r n ( ( 6 6 . 4 6 * pow ( 1 . 7 3 2 , ( lightFnom / 1 0 0 0. 0 ) ) ) − 1 3 3 . 5 ) ; }

## 2.5 Anschlusse Innensensoren ¨

## 2.6 Adapterplatine

## 2.7 Bodenfeuchtigkeitssensor

2https://github.com/TjarkG/biosphere-monitor/blob/main/Microcontroller/main.c (https://github.com/TjarkG/biosphere-monitor/blob/main/Microcontroller/main.c)

11

# Kapitel 3

# Software

Die Software besteht aus zwei Teilen, dem Code fur den Mikrocontroller und ¨ dem Ausleseprogramm fur den PC. Um die eine installieren und die andere ¨
nutzen zu können mussen beide zun ¨ | ächst gecloned und ihre abhängigkeiten
installiert werden. Die Befehle können fur Debian Linux Varianten einfach ¨
kopiert werden, fur andere Distributionen oder MacOS ist ¨ | sudo apt−get durch
das lokale Eqvivallent zu ersetzen

## 3.1 Instalation

Sämtliche benötigte Software kann durch ausfuhren von ¨

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

Installiert werden. Der Script wurde unter Ubuntu und Alpine Linux getestet. Falls dies nicht funktioniert kann die Installation auch manuel durchgefuhrt ¨ werden: Zum Clonen muss zunächst git installiert werden.

$ sudo apt−g e t i n s t a l l g i t

Dann kann das Repository gecloned

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

Und in den neuen Ortnder gewechselt werden.

$ cd bi o s p h e r e−monitor

Um die PC Software compilen zu können ist außerdem GCC als Kompiler notwendig.

$ sudo apt−g e t i n s t a l l gcc

Die aktuelle Version kann jetzt jeweils mit

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

kompilert und ausgefuhrt werden. ¨

| 12

Um die Mikrocontroller Firmware aktualisieren zu können, werden neben der Hardware (Abschnitt 2.1) eine ganze Reihe Hilfsprogramme benötigt. Eine Erläuterungen zu ihrer Funktion findet sich unter [12]

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

Das Upload der Firmware erfolgt mit

$ make program −C . / M i c r o c o n t r o l l e r

## 3.2 Mikrocontroller

## 3.3 PC

## 3.4 Scripte

Im Ordner Shell befinden sich zwei Scripte: install.sh ist der installationsscript der in Abschnitt 3.1 verwendet wurde. Dieser fuhrt die selben Schritte ¨ aus die auch dort beschrieben sind, ermittelt allerdings von selber den verwendeten Paketmanager.
Des weiteren ist kiosk.sh enthalten. Dieser Script hohlt sich einmal
pro Sekunde von biosphere.c die aktuellen Messwerte fur das Messger ¨ | ät an
/dev/ttyUSB0 und zeigt sie auf dem Terminal an.

13

# Literaturverzeichnis

[1] Tjark Gaudich, Biospher Monitor, github.com/TjarkG/biosphere-monitor
GitHub.com, 2021
[2] Prof. Dr. Lothar Meyer et al., Das große Tafelwerk interaktiv 2.0, Cornelsen Verlag, Berlin, 1. Auflage, 8. Druck 2018
[3] Microchip Technology Inc., ATxmega32A4U datasheet, www.microchip.com/downloads/en/DeviceDoc/ ATxmega128-64-32-16A4U-DataSheet-DS40002166A.pdf Microchip.com, 2011-2020
[4] Microchip Technology Inc., SST25VF040 datasheet, www.microchip.com/downloads/en/DeviceDoc/20005051E.pdf Microchip.com, 2005-2020
[5] Future Technology Devices International Limited, FT2323R datasheet, www.ftdichip.com/wp-content/uploads/2020/08/DS_FT232R.pdf ftdichip.com, 2020
[6] Texas Instruments Incorporated, LM35 datasheet, www.ti.com/lit/gpn/lm35
TI.com, 1999-2017
[7] Vishay Semiconductors, BPW96 datasheet, www.vishay.com/docs/81532/bpw96.pdf vishay.com, 2011
[8] Bosch Sensortec GmbH, BMP280 datasheet, www.bosch-sensortec.com/media/boschsensortec/downloads/ datasheets/bst-bmp280-ds001.pdf
bosch-sensortec.com, Oktober 2021
[9] Bosch Sensortec GmbH, BME280 datasheet, www.bosch-sensortec.com/media/boschsensortec/downloads/ datasheets/bst-bme280-ds002.pdf
bosch-sensortec.com, Oktober 2021

14

[10] Bosch Sensortec GmbH, BME680 datasheet, www.bosch-sensortec.com/media/boschsensortec/downloads/ datasheets/bst-bme680-ds001.pdf
bosch-sensortec.com, Januar 2021
[11] Brian W.Kernighan, Dennis M.Ritchie, The C Programming Language, Prentice Hall PTR, New Jersey, 2. Auflage, 58. Druck 2018
[12] Ubuntu Wiki, AVR,
https://wiki.ubuntuusers.de/AVR/
Ubuntu Deutschland e.V., Januar 2021

15

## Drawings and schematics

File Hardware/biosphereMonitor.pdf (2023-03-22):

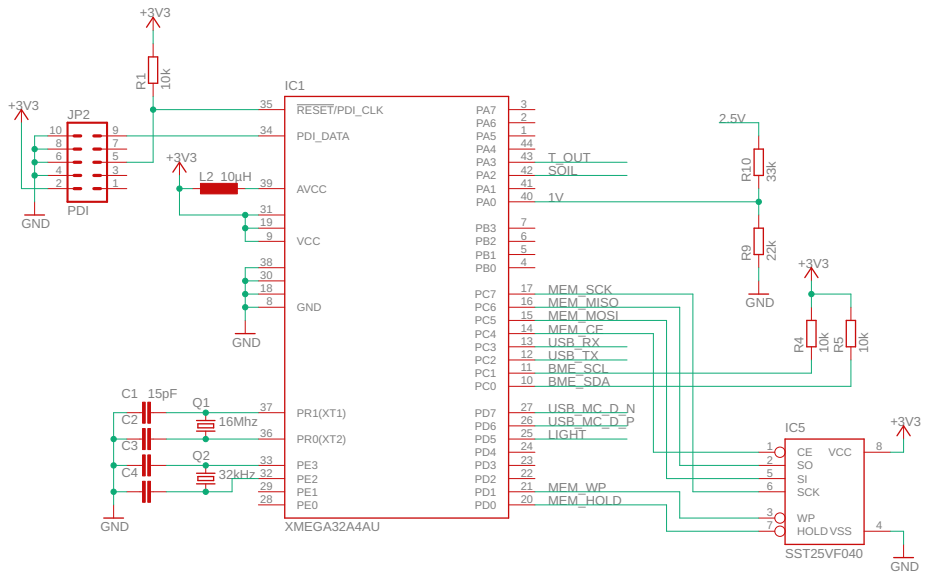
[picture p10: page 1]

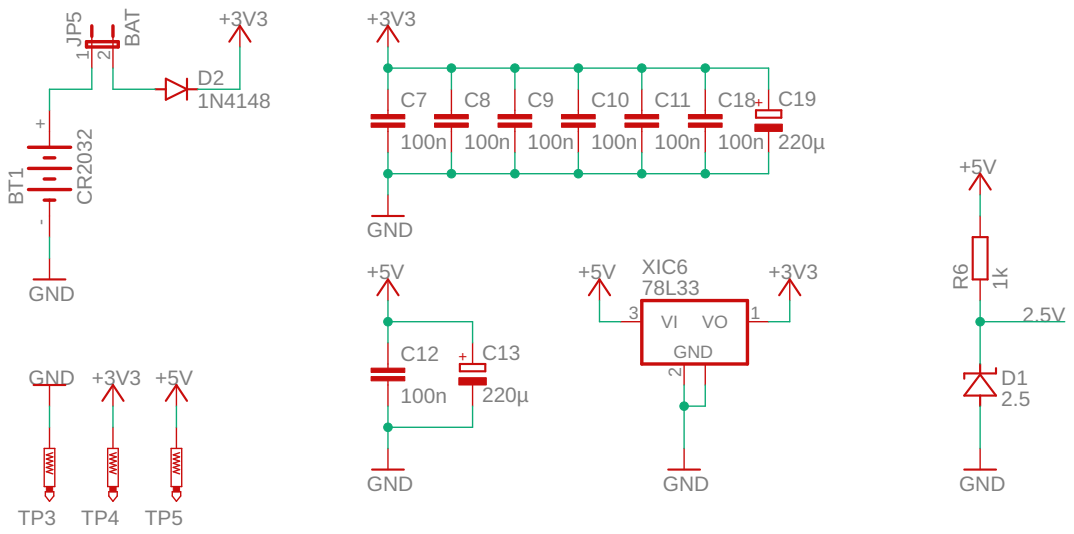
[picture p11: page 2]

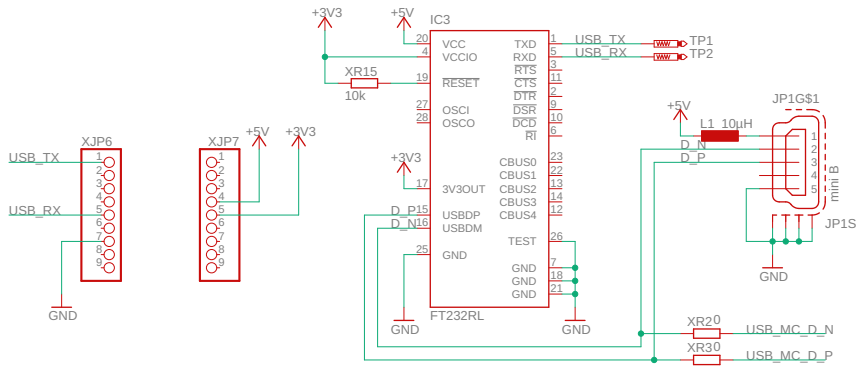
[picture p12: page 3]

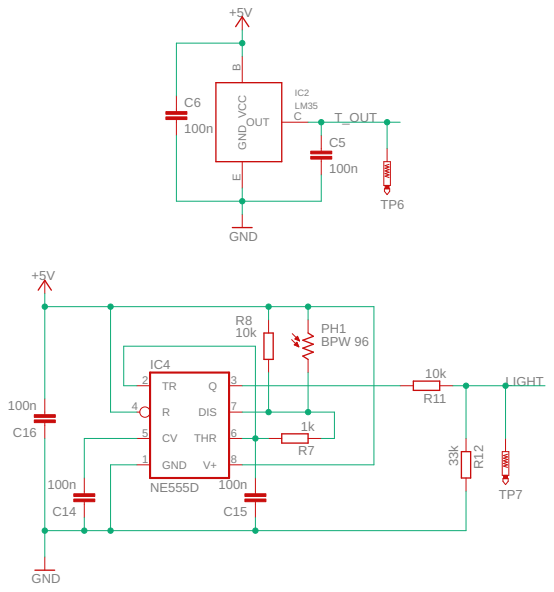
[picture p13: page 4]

6 | 1k

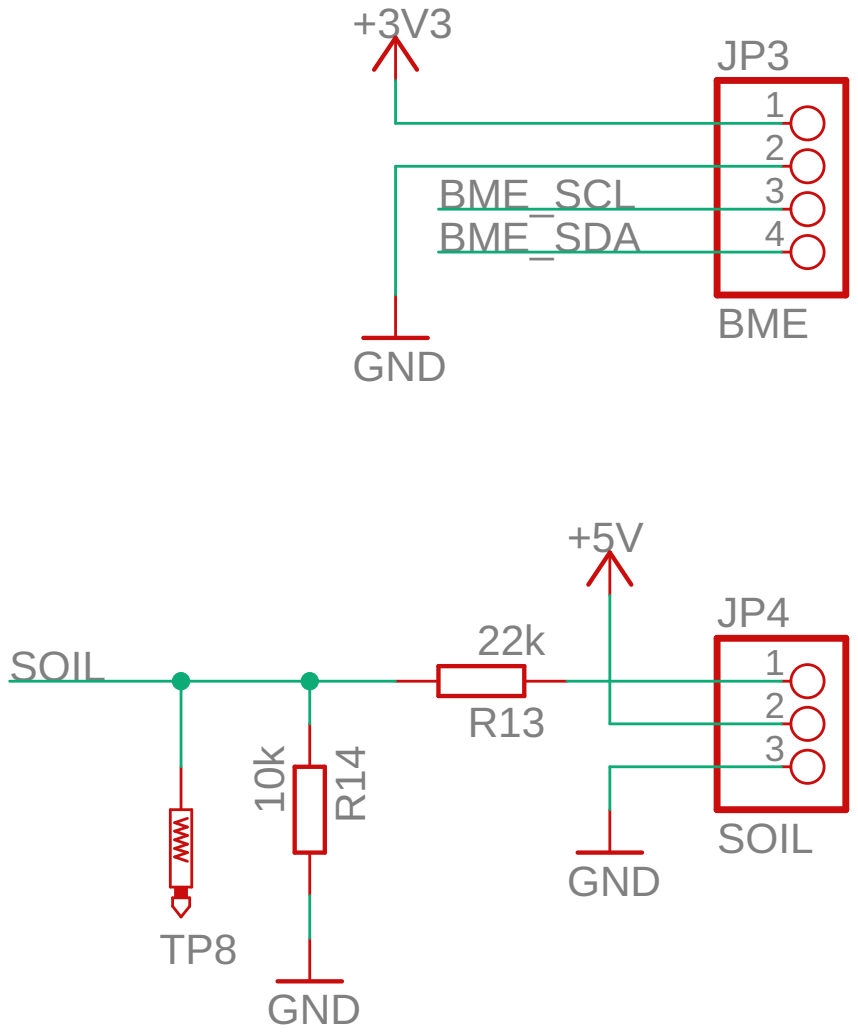
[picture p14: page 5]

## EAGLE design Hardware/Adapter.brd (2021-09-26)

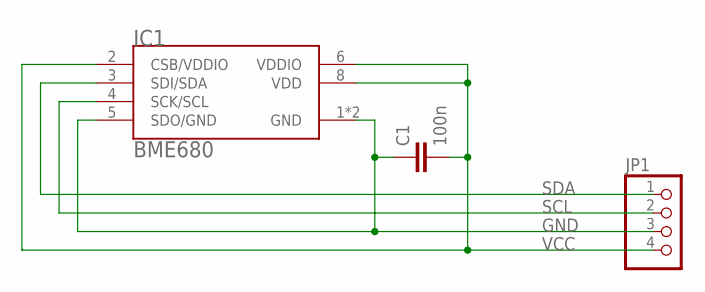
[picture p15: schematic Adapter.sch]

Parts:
C1: 100n; C0805
IC1: BME680; LGA8
JP1: PINHD-1X4; 1X04

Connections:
GND: C1.1, IC1.1 (GND), IC1.5 (SDO/GND), IC1.7 (GND), JP1.3
SCL: IC1.4 (SCK/SCL), JP1.2
SDA: IC1.3 (SDI/SDA), JP1.1
VCC: C1.2, IC1.2 (CSB/VDDIO), IC1.6 (VDDIO), IC1.8 (VDD), JP1.4

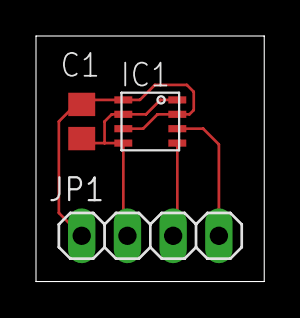
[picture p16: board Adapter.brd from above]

Board: 2 copper layers, 12.7 x 13.6 mm, 3 parts (0 on the bottom side), 4 nets.

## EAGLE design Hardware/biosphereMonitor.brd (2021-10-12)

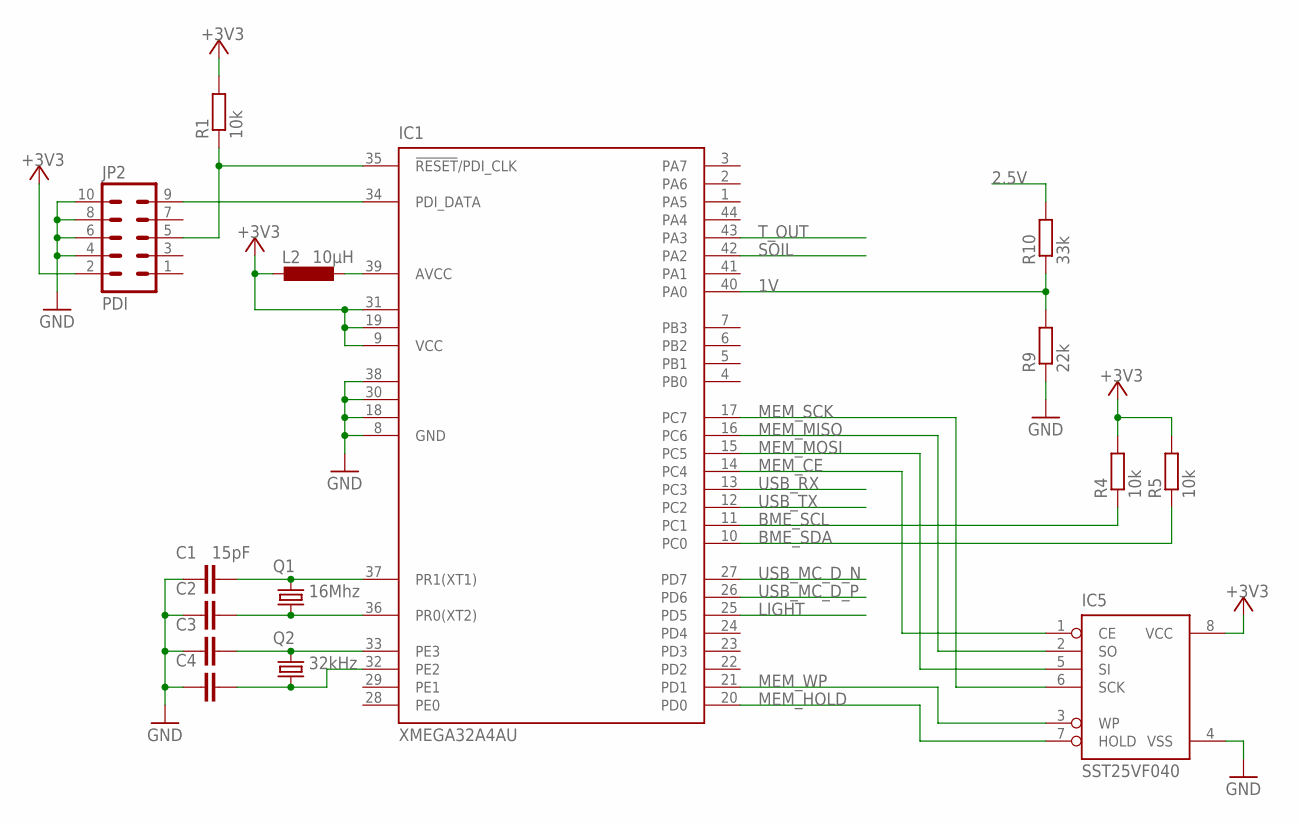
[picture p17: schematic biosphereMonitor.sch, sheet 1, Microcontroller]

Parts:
C1, C2, C3, C4: 15pF; C0805
IC1: XMEGA32A4AU; TQFP44
IC5: SST25VF040; SO08-208
JP2: PDI; ML10L
L2: 10µH; L2012C
Q1: 16Mhz; SM49
Q2: 32kHz; MS1V
R1, R4, R5: 10k; R0805
R9: 22k; R0805
R10: 33k; R0805

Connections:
1V: IC1.40 (PA0), R9.2, R10.1
2.5V: R10.2; also elsewhere on the board
+3V3: IC1.9 (VCC), IC1.19 (VCC1), IC1.31 (VCC2), IC5.8 (VCC), JP2.2, L2.1, R1.2, R4.2, R5.2; also elsewhere on the board
AVCC: IC1.39 (AVCC), L2.2
BME_SCL: IC1.11 (PC1), R4.1; also elsewhere on the board
BME_SDA: IC1.10 (PC0), R5.1; also elsewhere on the board
GND: C1.1, C2.1, C3.1, C4.1, IC1.8 (GND), IC1.18 (GND1), IC1.30 (GND2), IC1.38 (GND3), IC5.4 (VSS), JP2.4, JP2.6, JP2.8, JP2.10, R9.1; also elsewhere on the board
LIGHT: IC1.25 (PD5); also elsewhere on the board
MEM_CE: IC1.14 (PC4), IC5.1 (CE)
MEM_HOLD: IC1.20 (PD0), IC5.7 (HOLD)
MEM_MISO: IC1.16 (PC6), IC5.2 (SO)
MEM_MOSI: IC1.15 (PC5), IC5.5 (SI)
MEM_SCK: IC1.17 (PC7), IC5.6 (SCK)
MEM_WP: IC1.21 (PD1), IC5.3 (WP)
unnamed: IC1.35 (!RESET!/PDI_CLK), JP2.5, R1.1
unnamed: IC1.34 (PDI_DATA), JP2.9
unnamed: C1.2, IC1.37 (PR1(XT1)), Q1.2
unnamed: C2.2, IC1.36 (PR0(XT2)), Q1.1
unnamed: C3.2, IC1.33 (PE3), Q2.Q1 (1)
unnamed: C4.2, IC1.32 (PE2), Q2.Q2 (2)
SOIL: IC1.42 (PA2); also elsewhere on the board
T_OUT: IC1.43 (PA3); also elsewhere on the board
USB_MC_D_N: IC1.27 (PD7); also elsewhere on the board
USB_MC_D_P: IC1.26 (PD6); also elsewhere on the board
USB_RX: IC1.13 (PC3); also elsewhere on the board
USB_TX: IC1.12 (PC2); also elsewhere on the board

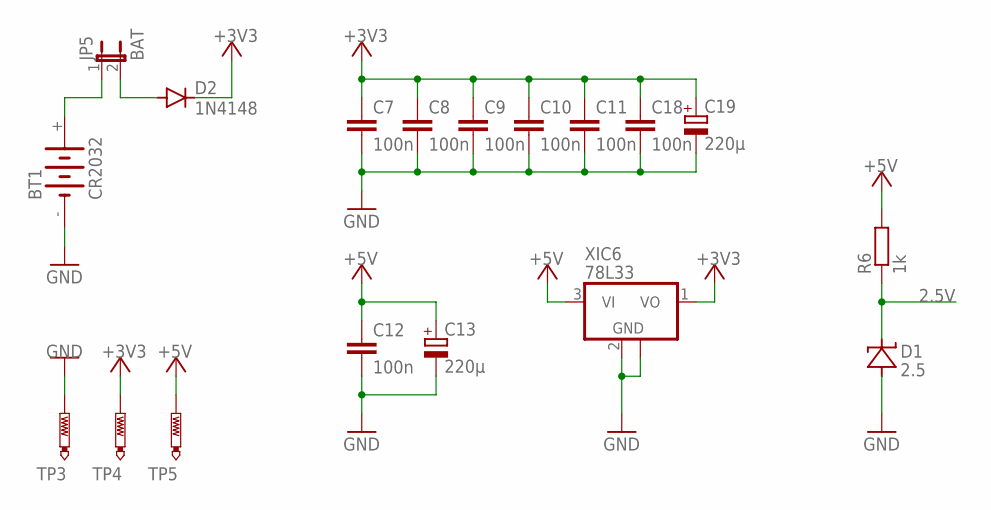
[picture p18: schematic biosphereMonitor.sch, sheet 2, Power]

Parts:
BT1: CR2032
C7, C8, C9, C10, C11, C12, C18: 100n; C0805
C13, C19: 220µ; PANASONIC_G
D1: 2.5; SOT23
D2: 1N4148; MINIMELF
JP5: BAT; JP1
R6: 1k; R0805
TP3, TP4, TP5: PTR1B2,54; B2,54
XIC6: 78L33; SOT89

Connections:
2.5V: D1.1 (C), R6.1; also elsewhere on the board
+3V3: C7.2, C8.2, C9.2, C10.2, C11.2, C18.2, C19.+, D2.C, TP4.TP, XIC6.1 (VO); also elsewhere on the board
+5V: C12.2, C13.+, R6.2, TP5.TP, XIC6.3 (VI); also elsewhere on the board
GND: BT1.-, C7.1, C8.1, C9.1, C10.1, C11.1, C12.1, C13.-, C18.1, C19.-, D1.2 (A), TP3.TP, XIC6.2 (GND), XIC6.2@1 (GND); also elsewhere on the board
unnamed: BT1.+, JP5.1
unnamed: D2.A, JP5.2

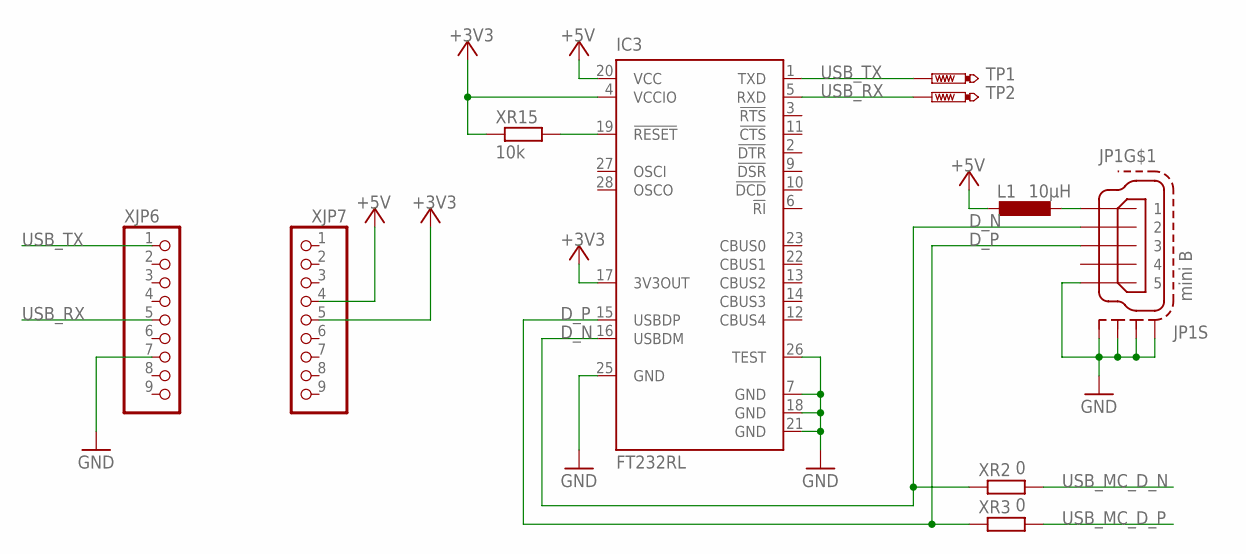
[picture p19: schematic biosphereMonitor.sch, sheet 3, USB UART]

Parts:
IC3: FT232RL; SSOP28
JP1: mini B; 32005-301
L1: 10µH; L2012C
TP1, TP2: PTR1B2,54; B2,54
XJP6, XJP7: PINHD-1X9; 1X09
XR2, XR3: 0; R0805
XR15: 10k; R0805

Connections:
+3V3: IC3.4 (VCCIO), IC3.17 (3V3OUT), XJP7.5, XR15.1; also elsewhere on the board
+5V: IC3.20 (VCC), L1.1, XJP7.4; also elsewhere on the board
D_N: IC3.16 (USBDM), JP1.2, XR2.1
D_P: IC3.15 (USBDP), JP1.3, XR3.1
GND: IC3.7 (GND), IC3.18 (GND), IC3.21 (GND), IC3.25 (GND), IC3.26 (TEST), JP1.5, JP1.M1 (S1), JP1.M2 (S2), JP1.M3 (S3), JP1.M4 (S4), XJP6.7; also elsewhere on the board
unnamed: JP1.1, L1.2
unnamed: IC3.19 (!RESET), XR15.2
USB_MC_D_N: XR2.2; also elsewhere on the board
USB_MC_D_P: XR3.2; also elsewhere on the board
USB_RX: IC3.5 (RXD), TP2.TP, XJP6.5; also elsewhere on the board
USB_TX: IC3.1 (TXD), TP1.TP, XJP6.1; also elsewhere on the board

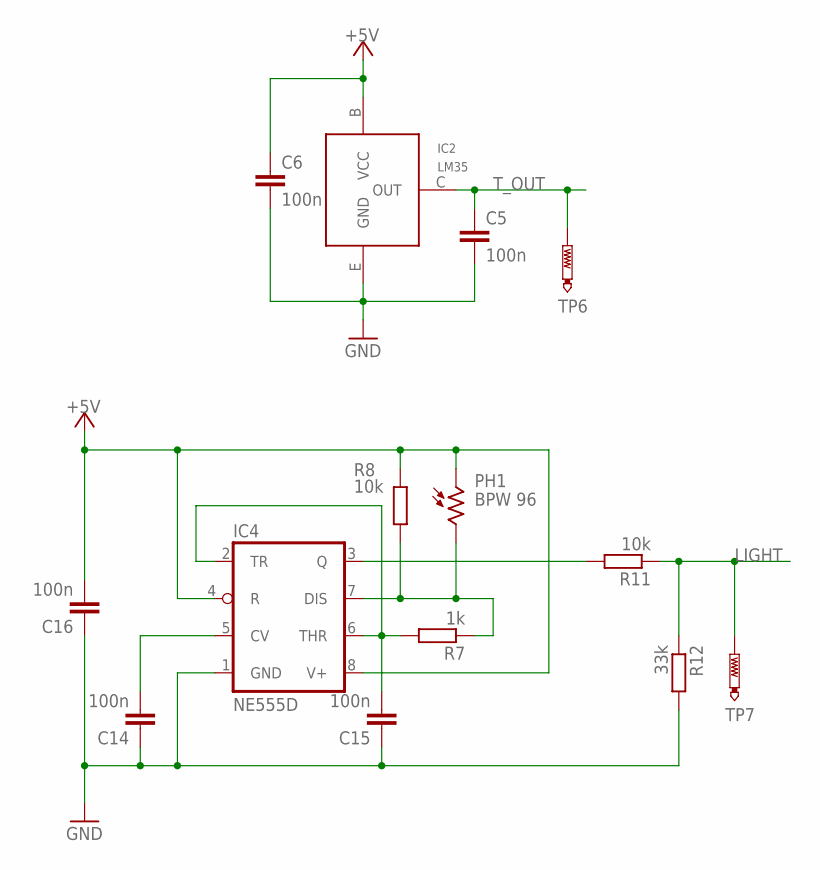
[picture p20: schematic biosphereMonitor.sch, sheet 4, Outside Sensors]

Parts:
C5, C6, C14, C15, C16: 100n; C0805
IC2: LM35; TO92-BCE
IC4: NE555D; SO08
PH1: BPW 96; T0-46-A10XX
R7: 1k; R0805
R8, R11: 10k; R0805
R12: 33k; R0805
TP6, TP7: PTR1B2,54; B2,54

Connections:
+5V: C6.2, C16.1, IC2.B (VCC), IC4.4 (R), IC4.8 (V+), PH1.1, R8.1; also elsewhere on the board
GND: C5.1, C6.1, C14.2, C15.2, C16.2, IC2.E (GND), IC4.1 (GND), R12.2; also elsewhere on the board
LIGHT: R11.1, R12.1, TP7.TP; also elsewhere on the board
unnamed: IC4.7 (DIS), PH1.2, R7.1, R8.2
unnamed: C14.1, IC4.5 (CV)
unnamed: C15.1, IC4.2 (TR), IC4.6 (THR), R7.2
unnamed: IC4.3 (Q), R11.2
T_OUT: C5.2, IC2.C (OUT), TP6.TP; also elsewhere on the board

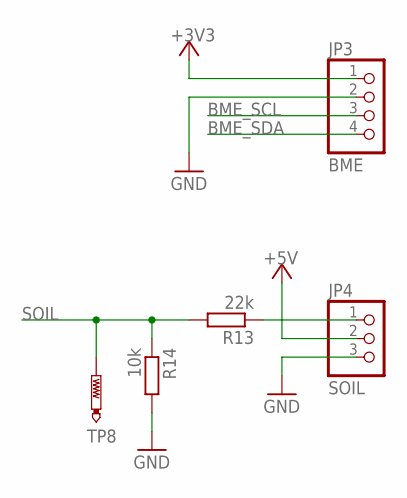
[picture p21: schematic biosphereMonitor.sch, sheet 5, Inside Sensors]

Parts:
JP3: BME; 1X04
JP4: SOIL; 1X03
R13: 22k; R0805
R14: 10k; R0805
TP8: PTR1B2,54; B2,54

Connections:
+3V3: JP3.1; also elsewhere on the board
+5V: JP4.2; also elsewhere on the board
BME_SCL: JP3.3; also elsewhere on the board
BME_SDA: JP3.4; also elsewhere on the board
GND: JP3.2, JP4.3, R14.2; also elsewhere on the board
unnamed: JP4.1, R13.1
SOIL: R13.2, R14.1, TP8.TP; also elsewhere on the board

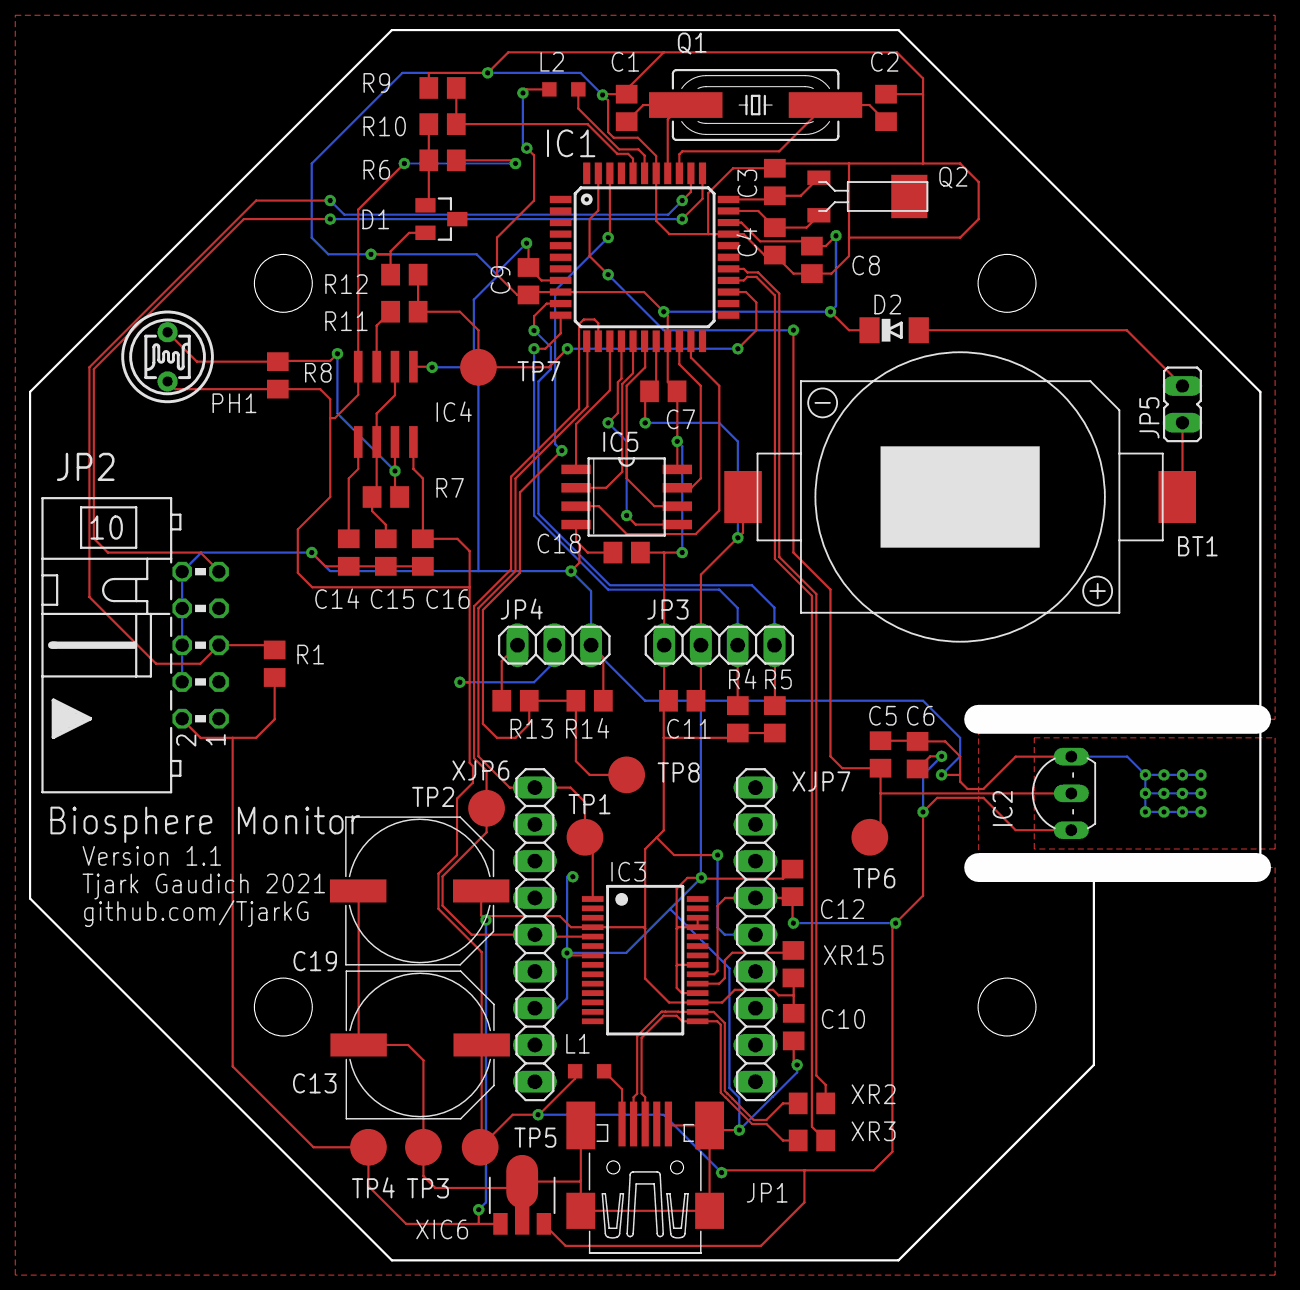
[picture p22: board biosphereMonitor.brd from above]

Board: 2 copper layers, 85.0 x 85.0 mm, 62 parts (0 on the bottom side), 38 nets.

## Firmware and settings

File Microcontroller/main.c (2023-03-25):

/*
 * biosphere-monitor/main.c
 *
 * Created: 26.08.2021 21:30:14
 * Author : Tjark Gaudich
 * Target : BiosphereMonitor.brd
 * Fuses:
 * avrdude -c avrispmkII -p atxmega32a4u -U fuse1:w:0x00:m -U fuse2:w:0xdf:m -U fuse4:w:0xfe:m -U fuse5:w:0xff:m
 * 
 * Initialization of a new Unit:
 * make biosphere && ./PC/biosphere /dev/ttyUSB0 -delete -f -ct23 -i60 -t -r
 */ 

#define BSCALE  0        //Baudrate: 1000000
#define BSEL    0
#define ADC_N   512      //Number of ADC readings taken per measurement

#include <avr/io.h>
#include <avr/interrupt.h>
#include <avr/eeprom.h>
#include <util/delay.h>
#include <string.h>
#include <stdlib.h>
#include <stdbool.h>

#include "../reading.h"
#include "ATxmegaAux.h"
#include "bme.h"
#include "spiFlash.h"

time_t timeCounter = 0;
volatile bool takeMeasurement = false;
volatile bool instruct = false;
char uartBuf[16];
uint16_t lightF = 0;
uint16_t lightFNom= 0;               //Frequency Counter Frequency in Hz

uint16_t EEMEM intervall = 600;     //sampling intervall in Seconds
uint8_t  EEMEM tOutOff = 0;         //Outside Temperature Offset in C*5 +128
uint32_t EEMEM flashAdr = 0;        //Address of the start of the last reading in the SPI Flash

uint16_t EEMEM lightOnTime = 0;     //light on Time
uint32_t EEMEM lightOffTime = 0;    //light off Time
uint32_t EEMEM lightThreshold = 0;   //Threshold under which light goes on (0 is always on)

#define setIntervall(new)   eeprom_update_word(&intervall, new)
#define getIntervall        eeprom_read_word(&intervall)
#define setTOutOff(new)     eeprom_update_byte(&tOutOff, new)
#define getTOutOff          eeprom_read_byte(&tOutOff)
#define setFlashAdr(new)    eeprom_update_dword(&flashAdr, new)
#define getFlashAdr         eeprom_read_dword(&flashAdr)

#define setLightOnTime(in)      eeprom_update_word(&lightOnTime, in)
#define getLightOnTime          eeprom_read_word(&lightOnTime)
#define setLightOffTime(in)     eeprom_update_dword(&lightOffTime, in)
#define getLightOffTime         eeprom_read_dword(&lightOffTime)
#define setLightThreshold(in)   eeprom_update_dword(&lightThreshold, in)
#define getLightThreshold       eeprom_read_dword(&lightThreshold)

struct reading getReading(void);
void printReading(struct reading in);
long selfDiagnosis(void);
void quicksort(uint16_t *data, uint16_t n);
uint16_t getMedian(uint16_t *rd, uint16_t n);
uint8_t getOutsideTemp(void);
uint16_t getLight(void);
uint16_t getExtCount(void);
uint8_t getRH(void);
uint32_t readingIt(struct reading *v, uint8_t i);

int main(void)
{
    clockExtern();
    PORTC.DIRSET = 0x08;
    PORTD.DIRSET = (1 << 3);
    RTC.PER = 3;
    rtc_init();

    PORTD.PIN5CTRL |= PORT_ISC_FALLING_gc;  //Frequency Counter initialization
    PORTD.INT0MASK |= (1 << 5);
    PORTD.INTCTRL = PORT_INT0LVL_LO_gc;

    ADCA_init();
    UART0_init();
    bmeInit();
    sei();
    flashInit();

    getReading();

    while (1)
    {
        if(takeMeasurement)
        {
            takeMeasurement = false;
            struct reading in = getReading();

            unsigned long adrTmp = getFlashAdr + sizeof(struct reading);     //Address of the new Reading
            if (adrTmp > (ADR_MAX - sizeof(struct reading)))
                adrTmp = 0;

            setFlashAdr(adrTmp);

            if (adrTmp % SECTOR_SIZE == 0)                 //Erase Sector if a new Sector is entert
                flashErase4kB(adrTmp);

            flashWrite(&in, sizeof(struct reading), adrTmp);
        }
        else if(instruct)
        {
            if (strncmp(uartBuf, "CR", 2) == 0)
                printReading(getReading());

            else if (strncmp(uartBuf, "AR", 2) == 0)
            {
                unsigned long adr = getFlashAdr;
                if (adr < ADR_MAX)
                    for (unsigned long i = 0; i <= adr; i += sizeof(struct reading))
                    {
                        struct reading in;
                        flashRead(&in, sizeof(struct reading), i);
                        printReading(in);
                    }
                uartWriteString("EOF\r\n");
            } else if (strncmp(uartBuf, "DEL", 3) == 0)
            {
                setFlashAdr(ADR_MAX);
                flashChipErase();
            } else if (strncmp(uartBuf, "OGT", 3) == 0)
                uartWriteIntLine(getTOutOff);
            else if (strncmp(uartBuf, "OST", 3) == 0)
                setTOutOff(strtol(uartBuf + 3, NULL, 10));
            else if (strncmp(uartBuf, "IG", 2) == 0)
                uartWriteIntLine(getIntervall);
            else if (strncmp(uartBuf, "IS", 2) == 0)
                setIntervall(strtol(uartBuf + 2, NULL, 10));
            else if (strncmp(uartBuf, "TG", 2) == 0)
                uartWriteIntLine(timeCounter);
            else if (strncmp(uartBuf, "TS", 2) == 0)
                timeCounter = strtol(uartBuf + 2, NULL, 10);
            else if (strncmp(uartBuf, "DR", 2) == 0)
                uartWriteIntLine(selfDiagnosis());
            else if (strncmp(uartBuf, "ID", 2) == 0)
                uartWriteIntLine(id);
            else if (strncmp(uartBuf, "RN", 2) == 0)
                uartWriteIntLine(getFlashAdr/sizeof(struct reading));
            else if (strncmp(uartBuf, "GH", 2) == 0)
                uartWriteIntLine(getExtCount());
            else if (strncmp(uartBuf, "GLN", 3) == 0)
                uartWriteIntLine(getLightOnTime);
            else if (strncmp(uartBuf, "SLN", 3) == 0)
                setLightOnTime(strtol(uartBuf + 3, NULL, 10));
            else if (strncmp(uartBuf, "GLF", 3) == 0)
                uartWriteIntLine(getLightOffTime);
            else if (strncmp(uartBuf, "SLF", 3) == 0)
                setLightOffTime(strtol(uartBuf + 3, NULL, 10));
            else if (strncmp(uartBuf, "GLT", 3) == 0)
                uartWriteIntLine(getLightThreshold);
            else if (strncmp(uartBuf, "SLT", 3) == 0)
                setLightThreshold(strtol(uartBuf + 3, NULL, 10));
            instruct = 0;
        }

        //check light conditions
        if((getLightOnTime < getLightOffTime ?
            (getLightOnTime < timeCounter%86400 && timeCounter%86400 < getLightOffTime) :
            (getLightOnTime < timeCounter%86400 || timeCounter%86400 < getLightOffTime))
            && (getLightThreshold == 0 || getLight() < getLightThreshold))
            PORTD.OUTSET = (1 << 3);
        else
            PORTD.OUTCLR = (1 << 3);
    }
}

struct reading getReading(void)     //returns fresh data
{
    struct reading in = {0};
    in.timeRead = timeCounter;
    in.temperaturOut = getOutsideTemp();
    in.light = getLight();
    in.humiditySoil = getRH();
    if(id > 0) //BME installed
    {
        in.temperaturIn = getBmeTemp();
        in.pressure = getBmePress();
    }
    if(id >=0x60)
        in.humidityAir = getBmeHumidity();
    return in;
}

void printReading(struct reading in)    //prints in to UART
{
    char str[16];
    for (uint8_t i = 0; i < 8; i++)
    {
        ultoa(readingIt(&in,i), str, 10);
        uartWriteString(str);
        if(i == 7)
            uartWriteString("\r\n");
        else
            uartWriteString(",");
    }
}

long selfDiagnosis(void)     //returns self diagnosis error code
{
    long errCode = 0;

    ADCA.CTRLA = ADC_ENABLE_bm;                     //Read Voltage at V_ref Pin. Should always be 4095 counts
    ADCA.CH1.CTRL |= ADC_CH_START_bm;
    while(!(ADCA.CH1.INTFLAGS & ADC_CH_CHIF_bm));
    ADCA.CH1.INTFLAGS = ADC_CH_CHIF_bm;
    if(ADCA.CH1.RES < 4090)
        errCode |= (1 << 1);
    ADCA.CTRLA &= ~ADC_ENABLE_bm;

    time_t timeTmp = timeCounter;                   //is the RTC running?
    _delay_ms(1010);
    if(timeCounter - timeTmp < 1)
        errCode |= (1 << 2);

    if(timeCounter < 1577833200)                    //is the RTC initialized (year after 2020)?
        errCode |= (1 << 3);

    if(flashID() != 0xBF258D)                      //Flash Signature as expected?
        errCode |= (1 << 4);

    if(flashAdr < (ADR_MAX - SECTOR_SIZE))                    //Flash read/write check only if last sector isn't already used
    {
        flashErase4kB(ADR_MAX - SECTOR_SIZE);
        uint8_t test = 0xAA;
        flashWrite(&test, 1, ADR_MAX - SECTOR_SIZE);
        flashRead(&test, 1, ADR_MAX - SECTOR_SIZE);
        if(test == 0xFF)                            //Not Erased properly
            errCode |= (1 << 5);
        if(test != 0xAA)                            //Read or Write went wrong
            errCode |= (1 << 6);
        flashErase4kB(ADR_MAX - SECTOR_SIZE);
    }

    if(!(PORTC.IN & (1 << 2)))                      //UART Rx and Tx should be high when nothing is transmitted
        errCode |= (1 << 7);
    if(!(PORTC.IN & (1 << 3)))
        errCode |= (1 << 8);

    unsigned char tTmp = getOutsideTemp();          //Temperatur Sensor Plausibility
    if(tTmp == 0 || tTmp > 250)
        errCode |= (1 << 9);

    if(lightFNom < 1100 || lightFNom > 10000)       //Light Frequency Range
        errCode |= (1 << 10);

    if(getIntervall == UINT16_MAX)                  //Sampling Intervall not set
        errCode |= (1 << 11);

    if(getTOutOff == UINT8_MAX)                     //Temperatur Offset not set
        errCode |= (1 << 12);

    if(id == 0)                                     //BME Connected?
        errCode |= (1 << 13);
    else                                            //BME Readings in range?
    {
        if(getBmeTemp() == 0 || getBmeTemp()  > 850 || getBmePress() < 3000 || getBmePress()  > 11000)
            errCode |= (1 << 14);
    }
    return errCode;
}

void quicksort(uint16_t *data, uint16_t n)       //sorts data till n ascending
{
  if (n < 2) return;

  uint16_t pivot = data[n / 2];

  int16_t i, j;
  for (i = 0, j = (int16_t) n - 1; ; i++, j--)
  {
    while (data[i] < pivot) i++;
    while (data[j] > pivot) j--;

    if (i >= j) break;

    uint16_t temp = data[i];
    data[i]     = data[j];
    data[j]     = temp;
  }

  quicksort(data, i);
  quicksort(data + i, n - i);
}

uint16_t getMedian(uint16_t *rd, const uint16_t n)   //returns Median of the Values in rd to rd[n]
{
    quicksort(rd, n);
	return n % 2 ? rd[n / 2] : (rd[n / 2 - 1] + rd[n / 2]) / 2;
}

uint8_t getOutsideTemp(void)  //returns Outside Temperatur in °C*5
{
    ADCA.CTRLA = ADC_ENABLE_bm;
    uint16_t tempArr[ADC_N];
    for(uint16_t i = 0; i < ADC_N; i++)
	{
		ADCA.CH0.CTRL |= ADC_CH_START_bm;
        while(!(ADCA.CH0.INTFLAGS & ADC_CH_CHIF_bm));
        ADCA.CH0.INTFLAGS = ADC_CH_CHIF_bm;
        tempArr[i] = ADCA.CH0.RES;
	}
    ADCA.CTRLA &= ~ADC_ENABLE_bm;
    return (getMedian(tempArr, ADC_N) / 8) + getTOutOff - 128;
}

uint16_t getLight(void)                         //returns illuminate in lux
{
    if(lightFNom < 1200)                        //Sensor cutoff Frequency
        return 0;
    return (unsigned int) ((66.46 * pow(1.732, (lightFNom / 1000.0)) ) - 133.5);
}

uint8_t getRH(void)                             //returns relativ humidity from external moisture sensor
{
    int16_t rh = 208 - (int16_t) (getExtCount()/7);       //f(x) = -1/7x+208
    return (rh > 100 || rh < 0) ? 0 : rh;
}

uint16_t getExtCount(void)  //returns ADC count from external Sensor
{
    ADCA.CTRLA = ADC_ENABLE_bm;
    uint16_t tempArr[ADC_N];
    for(uint16_t i = 0; i < ADC_N; i++)
	{
		ADCA.CH2.CTRL |= ADC_CH_START_bm;
        while(!(ADCA.CH2.INTFLAGS & ADC_CH_CHIF_bm));
        ADCA.CH2.INTFLAGS = ADC_CH_CHIF_bm;
        tempArr[i] = ADCA.CH2.RES;
	}
    ADCA.CTRLA &= ~ADC_ENABLE_bm;
    return getMedian(tempArr, ADC_N);
}

uint32_t readingIt(struct reading *v, uint8_t i) //makes it possible to iterate through a reading
{
    switch(i)
    {
        case 0: return v->timeRead;
        case 1: return v->light;
        case 2: return v->temperaturOut;
        case 3: return v->temperaturIn;
        case 4: return v->pressure;
        case 5: return v->humidityAir;
        case 6: return v->humiditySoil;
        default: return 0;
    }
}

ISR(USARTC0_RXC_vect)       //UART ISR
{
    char Data = USARTC0.DATA;
    USARTC0.DATA = Data;
    if(Data == '\r')
        USARTC0.DATA = '\n';
    static unsigned char i = 0;
    uartBuf[i] = Data;
    if(i == 15 || Data == '\r')
    {
        uartBuf[i] = '\0';
        instruct = true;
        i = 0;
    }
    else
        i++;
}

ISR(RTC_OVF_vect)          //RTC ISR
{
    timeCounter++;
    lightFNom = lightF;
    lightF = 0;
    if((timeCounter % getIntervall) == 0)
        takeMeasurement = true;
}

//ISR for Frequency Counter
ISR(PORTD_INT0_vect)
{
    lightF++;
}

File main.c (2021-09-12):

/*
 * biosphere-monitor/main.c
 *
 * Created: 26.08.2021 21:30:14
 * Author : Tjark Gaudich
 * Target : BiosphereMonitor.brd
 */ 

#ifndef __AVR_ATxmega16A4U__
#define __AVR_ATxmega16A4U__
#endif

#define F_CPU 16000000UL
#define BSCALE  -5
#define BSEL    246
#define ADCN    256       //Number of ADC readings taken per Messurment

#include <avr/io.h>
#include <avr/interrupt.h>
#include <util/delay.h>
#include <time.h>
#include <stdbool.h>
#include <avr/eeprom.h> 
#include <avr/pgmspace.h>
#include <stddef.h>
#include <avr/sleep.h>
#include <string.h>
#include <stdlib.h>
#include <stdio.h>
#include "ATxmega_help.h"
#include "itoa.h"
#include "reading.h"
#include "bme.h"

uint32_t timeCounter = 0;
volatile bool takeMessurment = false;
volatile bool instruct = false;
char uartBuf[16];
char sensType;
unsigned int  EEMEM intervall = 600;     //sampling intervall in Seconds
unsigned char EEMEM soilSensor = 0;      //is a Soil Sensor connected (bool)
unsigned char EEMEM tOutOff = 0;         //Outside Temperature Offset in C*5 +128
unsigned char EEMEM tInOff = 0;          //Inside Temperature Offset in C*5 +128

#define setIntervall(new)   eeprom_update_word(&intervall, new)
#define getIntervall        eeprom_read_word(&intervall)
#define setSoilSensor(new)  eeprom_update_byte(&soilSensor, new)
#define hasSoilSensor       eeprom_read_byte(&soilSensor)
#define settOutOff(new)     eeprom_update_byte(&tOutOff, new)
#define gettOutOff          (eeprom_read_byte(&tOutOff))
#define settInOff(new)     eeprom_update_byte(&tInOff, new)
#define gettInOff          (eeprom_read_byte(&tInOff))

struct reading getReading(void);
void printReading(struct reading in);
int selfDiagnosse(void);
void quicksort(unsigned int *data, unsigned int n);
unsigned int getMedian(unsigned int *rd, const unsigned int n);
unsigned char getOutsideTemp(void);
unsigned int getLight(void);
unsigned char getSoilHum(void);

int main(void)
{
    SET_CLK_EXTERN;
    PORTC.DIRSET = 0x08;
    RTC.PER = 3;
    RTC_INIT;
    ADC0_INIT;
    UART0INIT;
    sensType = bmeInit();
    sei();
    set_sleep_mode(SLEEP_MODE_EXT_STANDBY);
    uartWriteString("BT\r\n");
    _delay_ms(10);
    sleep_enable();

    while (1)
    {
        if(!(PORTD.IN & (1<<0)))
        {
            //PORTC.DIRCLR = 0x08;
            //sleep_enable();
            //sleep_cpu();
        }
        else if(takeMessurment)
        {
            takeMessurment = false;
            PORTC.DIRSET = 0x08;
            struct reading in = getReading();
            //printReading(in);
            in.iaq++;
            //TODO: Store Reading on SD Card
            _delay_ms(10);
        }
        else if(instruct)
        {
            PORTC.DIRSET = 0x08;
            if(strncmp(uartBuf,"CR",2) == 0)
            {
                struct reading in = getReading();
                printReading(in);
            }
            else if(strncmp(uartBuf,"AR",2) == 0)
            {
                //TODO:print readings
                for(int i = 0; i<10; i++)
                {
                    struct reading in = getReading();
                    printReading(in);
                }
                uartWriteString("EOF\r\n");
            }
            else if(strncmp(uartBuf,"OGT",3) == 0)
                uartWriteIntLine(gettOutOff);
            else if(strncmp(uartBuf,"OST",3) == 0)
                settOutOff(atoi(uartBuf+3));
            else if(strncmp(uartBuf,"OGI",3) == 0)
                uartWriteIntLine(gettInOff);
            else if(strncmp(uartBuf,"OSI",3) == 0)
                settInOff(atoi(uartBuf+3));
            else if(strncmp(uartBuf,"IG",2) == 0)
                uartWriteIntLine(getIntervall);
            else if(strncmp(uartBuf,"IS",2) == 0)
                setIntervall(atoi(uartBuf+2));
            else if(strncmp(uartBuf,"SG",2) == 0)
                uartWriteIntLine(hasSoilSensor);
            else if(strncmp(uartBuf,"SS",2) == 0)
                setSoilSensor(atoi(uartBuf+2));
            else if(strncmp(uartBuf,"TG",2) == 0)
                uartWriteIntLine(timeCounter);
            else if(strncmp(uartBuf,"TS",2) == 0)
                timeCounter = atol(uartBuf+2);
            else if(strncmp(uartBuf,"DR",2) == 0)
                uartWriteIntLine(selfDiagnosse());
            instruct = 0;
        }
    }
}

struct reading getReading(void)     //reuturns fresh data
{
    struct reading in = {0,0,0,0,0,0,0,0};
    in.timeRead = timeCounter;
    in.temperaturOut = getOutsideTemp();
    in.light = getLight();
    in.humiditySoil = getSoilHum();
    if(sensType > 0)
    {
        in.temperaturIn = getBmeTemp();
        in.pressure = getBmePress();
    }
    return in;
}

void printReading(struct reading in)    //prints in to UART
{
    char str[16];
    for (char i = 0; i < 8; i++)
    {
        _itoa(readingIt(&in,i), str);
        uartWriteString(str);
        if(i == 7)
            uartWriteString("\r\n");
        else
            uartWriteString(",");
    }
}

int selfDiagnosse(void)     //returns self diagnosis errorcode
{
    if(getOutsideTemp() == 0 || getOutsideTemp() > 250)
        return 1;
    if(getBmeTemp() == 0 || getBmeTemp()  > 850)
        return 2;
    if(getBmePress() < 300 || getBmePress()  > 1100)
        return 3;
    return 0;
}

void quicksort(unsigned int *data, unsigned int n)       //sorts data till n ascending
{
  if (n < 2) return;
 
  int pivot = data[n / 2];
 
  int i, j;
  for (i = 0, j = n - 1; ; i++, j--)
  {
    while (data[i] < pivot) i++;
    while (data[j] > pivot) j--;
 
    if (i >= j) break;
 
    int temp = data[i];
    data[i]     = data[j];
    data[j]     = temp;
  }
 
  quicksort(data, i);
  quicksort(data + i, n - i);
}

unsigned int getMedian(unsigned int *rd, const unsigned int n)   //returns Median of the Values in rd to rd[n]
{
	//linSort(rd, n);
    quicksort(rd, n);
	return n % 2 ? rd[n / 2] : (rd[n / 2 - 1] + rd[n / 2]) / 2;
}

unsigned char getOutsideTemp(void)  //returns Outside Temperatur in °C*5
{
    ADCA.CTRLA = ADC_ENABLE_bm;
    unsigned int tempArr[ADCN];
    for(int i = 0; i<ADCN; i++)
	{
		ADCA.CH0.CTRL |= ADC_CH_START_bm;
        while(!(ADCA.CH0.INTFLAGS & ADC_CH_CHIF_bm));
        ADCA.CH0.INTFLAGS = ADC_CH_CHIF_bm;
        tempArr[i] = ADCA.CH0.RES;
	}
    ADCA.CTRLA &= ~ADC_ENABLE_bm;
    return (getMedian(tempArr, ADCN)/8)+gettOutOff-128;
}

unsigned int getLight(void)  //returns iluminace in lux
{
    ADCA.CTRLA = ADC_ENABLE_bm;
    unsigned int tempArr[ADCN];
    for(int i = 0; i<ADCN; i++)
	{
		ADCA.CH1.CTRL |= ADC_CH_START_bm;
        while(!(ADCA.CH1.INTFLAGS & ADC_CH_CHIF_bm));
        ADCA.CH1.INTFLAGS = ADC_CH_CHIF_bm;
        tempArr[i] = ADCA.CH1.RES;
	}
    ADCA.CTRLA &= ~ADC_ENABLE_bm;
    return getMedian(tempArr, ADCN);
}
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

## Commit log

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2021-08-29 added Intervall and ADC Reading
    [InterfaceStandard.csv]
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2021-08-31 added CSV generation
    [biosphere.csv]
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2021-08-31 added standard interface to MC
    [InterfaceStandard.csv]
2021-09-01 changed Helpfile Source
    [biosphere.csv]
2021-09-01 added Help Formating
    [biosphere.csv]
2021-09-01 changed Baud Rate to 115200
    [biosphere.csv]
2021-09-01 added feedback for each Option
    [biosphere.csv]
2021-09-01 tiedied up MC Code
    [biosphere.csv]
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2021-09-04 added cost estimate
    [Cost_Estimate.ods, biosphere.csv]
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2021-09-06 fixed Sensor readout not working
2021-09-06 added power supply to Cost Estimate
    [Cost_Estimate.ods]
2021-09-06 added basic offset correction
    [biosphere.csv]
2021-09-07 new readings
    [biosphere.csv]
2021-09-07 added schematic
    [biosphereMonitor.sch]
2021-09-07 added Outside Temperatur Calibration
    [InterfaceStandard.csv, biosphere.csv]
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2021-09-09 added adc input for humidity and illuminance
    [biosphere.csv, biosphereMonitor.sch]
2021-09-09 added error managment to getReading function
    [biosphere.c]
2021-09-12 Defined Board Shape
    [biosphere.csv, biosphereMonitor.brd, biosphereMonitor.sch]
2021-09-12 changed Sorting from Linsort to Quicksort
    [biosphere.csv]
2021-09-13 Sorted Project in Directorys
    [biosphere.csv]
2021-09-13 added file opening for calculator
    [in.csv]
2021-09-15 eliminat now dircetly accepts array of points
    [biosphere.csv]
2021-09-15 messured different Brightneses
    [Lux Messurments.ods]
2021-09-16 added light sensor to schematic
    [biosphereMonitor.brd, biosphereMonitor.sch]
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2021-09-17 added reference in schematic
    [biosphereMonitor.brd, biosphereMonitor.sch]
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2021-09-18 added messurments
    [Lux Messurments.ods]
2021-09-19 added additional set of messurments with frequency
    [Lux Messurments.ods]
2021-09-19 added exponetial aproximation
    [Lux Messurments.ods]
2021-09-20 added calculation of exponential functions
    [in.csv]
2021-09-20 put messurments in in.csv
    [in.csv]
2021-09-21 changed light Sensor to frequency Messurment
    [biosphereMonitor.brd, biosphereMonitor.sch]
2021-09-22 added lux messurment
    [biosphereMonitor.brd, biosphereMonitor.sch, in.csv]
2021-09-22 added humidity conversion to percent and completed schematic
    [biosphereMonitor.brd, biosphereMonitor.sch]
2021-09-22 placed Parts
    [biosphereMonitor.brd, biosphereMonitor.sch]
2021-09-22 routed board
    [biosphereMonitor.brd]
2021-09-24 added PCB options and cam file
    [biosphereMonitor.brd, biosphereMonitor.sch]
2021-09-24 added option for external ftdi board
    [biosphereMonitor.brd, biosphereMonitor.sch]
2021-09-24 changed some footprints
    [biosphereMonitor.brd, biosphereMonitor.sch]
2021-09-25 filled groundplane
    [biosphereMonitor.brd]
2021-09-26 completed saving of readings to flash
    [InterfaceStandard.csv, Lux Messurments.ods, biosphere.csv]
2021-09-26 added BME 680 Temperature readout
    [Adapter.brd, Adapter.sch]
2021-09-26 added other BME functions (gas resistence not working yet)
    [Adapter.brd, biosphere.csv]
2021-09-27 toke one night of messurments
    [biosphere.csv]
2021-09-27 changed decimal Seperator in Output File to Comma
    [biosphere.csv]
2021-10-08 optimized layout optics
    [biosphereMonitor.brd]
2021-10-11 removed manual setting of soil sensor state
    [InterfaceStandard.csv]
2021-10-11 removed unnecesary parts
    [biosphereMonitor.brd, biosphereMonitor.sch]
2021-10-12 moved components away from screws
    [biosphereMonitor.brd]
2021-10-12 improved selftest
    [biosphereMonitor.brd, biosphereMonitor.sch]
2021-10-12 played around with 3d models
    [biosphereMonitor.brd, biosphereMonitor.sch]
2021-10-12 changed rx with tx
    [biosphereMonitor.brd, biosphereMonitor.sch]
2021-10-13 fixed inside temperature caluclation for csv output
    [biosphere.csv]
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2021-10-14 added correction factor for BMX280
    [biosphere.csv]
2021-10-14 reverted last commit
    [biosphere.csv]
2021-10-18 added status bar when saving readings
    [biosphere.csv]
2021-10-23 bits read from Sensor are now in the right order
    [biosphere.csv]
2021-10-23 tiedied up Temperatur and Pressur Code
    [biosphere.csv]
2021-10-24 improved readout for BME 680
    [biosphere.csv]
2021-10-25 moved PCB files into folder
    [Adapter.brd, Adapter.sch, biosphereMonitor.brd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]
2021-10-25 adjusted Light Messurment for PCBA in an Enclousur
    [Lux Messurments.ods, in.csv]
2021-11-03 added final function for lux messurment
    [Lux Messurments.ods]
2021-11-03 updated cost estimate
    [Cost_Estimate.ods]
2021-11-28 sortet Files
    [Cost_Estimate.ods, InterfaceStandard.csv, Lux Messurments.ods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]
2021-11-28 added 3d models
    [Adapter.brd, Adapter.sch, Cap.stl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]
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2021-12-08 started adding explination for light Sensor
    [Lux Messurments.ods]
2021-12-08 replaced calc by explanation in Manual
    [in.csv]
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2021-12-11 produced new sample output
    [Sample_Output.csv, Sample_biosphere.csv]
2021-12-12 added edgecase for reading out right after deleting flash
    [InterfaceStandard.csv]
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2021-12-20 added option to get ADC reading of external sensor
    [InterfaceStandard.csv]
2021-12-20 fixed formating of -gh option
    [biosphere.c]
2021-12-21 added transfer function for soil humidity
    [RH Messurments.ods]
2022-01-15 filed gaps in sampel
    [Sample_Output.csv]
2022-01-15 reformated Interface Standard
    [InterfaceStandard.csv]
2022-01-20 Added Missing Brackets
2022-01-20 added command to convert to xlsx and example document
    [Sample_Output.xlsx]
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2022-03-06 fixed lnCnt of by one
    [biosphere.c]
2022-03-09 fixed wrong formular for rh soil
    [RH Messurments.ods]
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2022-08-16 fixed selftest with new pressure range
    [main.c]
2022-08-18 fixed broken flash code
    [main.c]
2022-08-28 fixed uncomplet deletion issue
    [main.c]
2022-10-30 added lamp functions to microcontroller
    [InterfaceStandard.csv]
2022-10-31 fixed formating and strncmp lengths
    [cli.cpp]
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2022-12-20 fixed warnings, replaced nonstandard functions
    [main.c]
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2023-03-25 fixed reading flash returning garbage & getID hanging
    [InterfaceStandard.csv]
